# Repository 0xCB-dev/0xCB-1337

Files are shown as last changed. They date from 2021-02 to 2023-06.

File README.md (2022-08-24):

# 0xcb-1337
## Mechanical macropad with OLED running QMK

Licence | OSHWA
:-------------------------:|:-------------------------:
 | (https://certification.oshwa.org/de000121.html)

### Available here:

[KeebSupply](https://keeb.supply/products/0xcb-1337)

### QMK:

[keyboards/0xcb/1337/](https://github.com/qmk/qmk_firmware/tree/master/keyboards/0xcb/1337)

#### Flashing:

* `qmk clone`
* `cd qmk_firmware`
* `export LTO=Y`
* Press switch 1 while plugging in to go into dfu mode (or the reset button)
* `make 0xcb/1337:via:flash`

### Assembly:

You can use the [humanpnp](https://files.0xcb.dev/0xCB-1337/humanpnp.html) to easily place components.

### PCB:
KiCad 6 stable release - using these [libs](https://github.com/0xCB-dev/0xcb-libs)

[Schematic](https://github.com/0xCB-dev/0xcb-1337/blob/main/rev4.0/1337-v4.0.pdf)

Top | Bottom
:-------------------------:|:-------------------------:
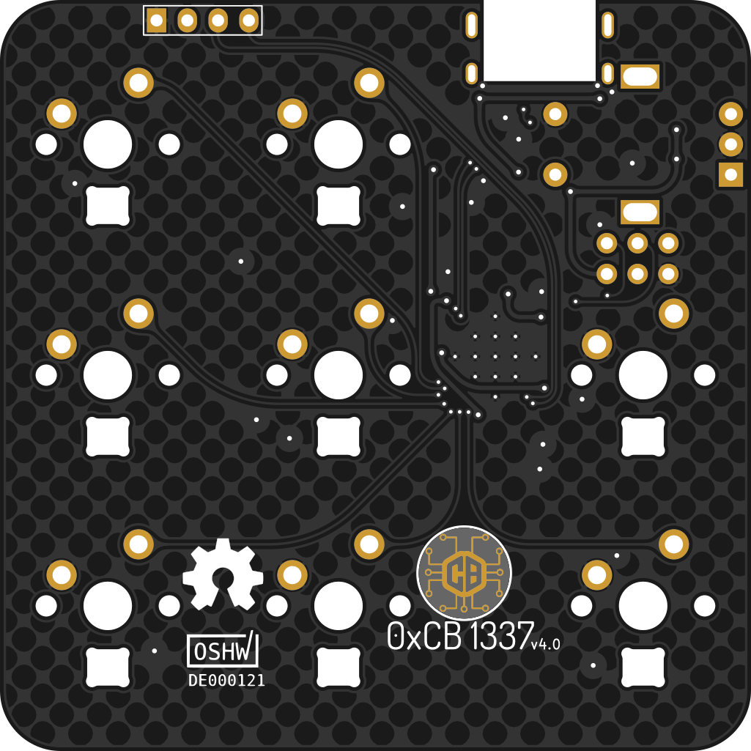
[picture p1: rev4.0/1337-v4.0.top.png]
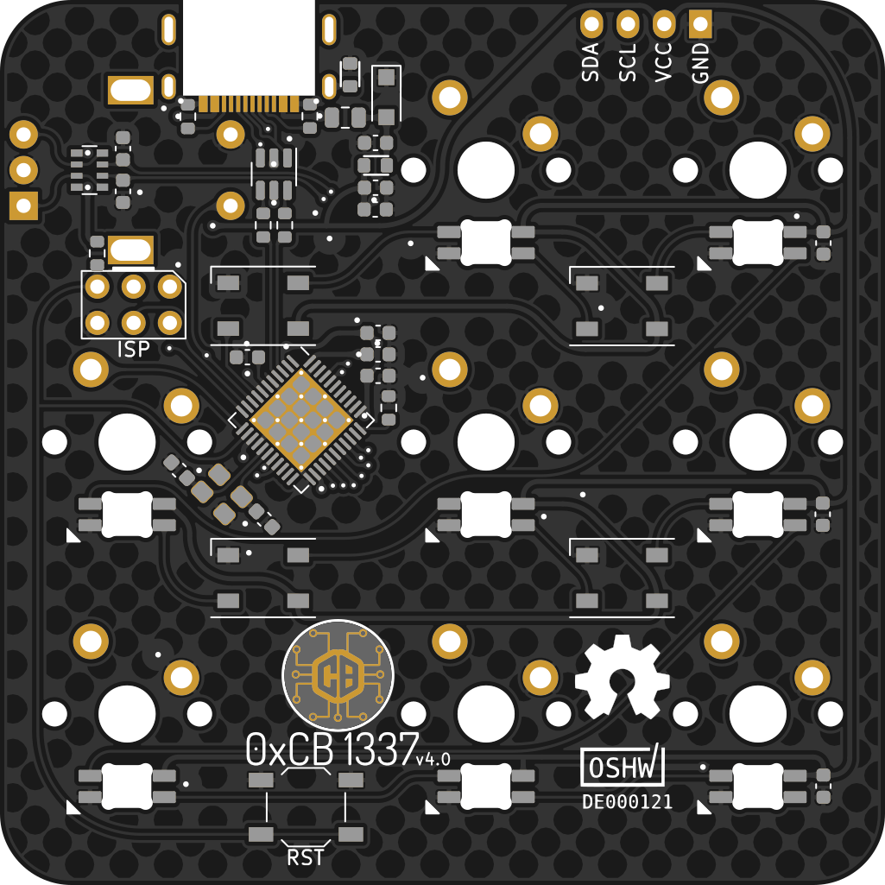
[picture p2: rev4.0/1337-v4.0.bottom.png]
  |  

### Case 3D files:

[STLs](https://github.com/0xCB-dev/0xcb-1337/tree/main/rev4.0/case/STL)

### PCB 3D files:

[FreeCAD](https://github.com/0xCB-dev/0xcb-1337/tree/main/rev4.0/1337-freecad.FCStd)

[STEP](https://github.com/0xCB-dev/0xcb-1337/tree/main/rev4.0/1337-v4.0.step)

[WRL](https://github.com/0xCB-dev/0xcb-1337/tree/main/rev4.0/1337-v4.0.wrl)

#### BOM:
 References                        | Value        | Quantity | Part Nb.            
-----------------------------------|--------------|----------|---------------------
 C2, C4, C6, C7, C8, C10, C12, C14 | 100n         | 8        | C478888             
 C3, C5, C9                        | 1u           | 3        | C29936              
 C11, C13                          | 22p          | 2        | C85969              
 C1                                | 10u          | 1        | C85713              
 R1, R2                            | 5.1k         | 2        | C23186              
 R3, R4                            | 22           | 2        | C174301             
 R5, R6                            | 10k          | 2        | C98220              
 D1, D2, D3, D4, D5, D6, D7, D8    | SK6812MINI-E | 8        | SK6812MINI-E        
 D10, D11, D12, D13                | WS2812B      | 4        | C114586             
 D9                                | SMF5.0CA     | 1        |  576-SMF5.0CA       
 U2                                | USBLC6-2SC6  | 1        | C7519               
 U3                                | ATMEGA32U4   | 1        | ATMEGA32U4RC-MU-ND  
 Y1                                | 16MHz        | 1        | C389842             
 F1                                | 1A           | 1        | C369150             
 SW1                               | SW_Push      | 1        | C318884             
 FB1, FB2                          | 600R         | 2        | C74330              
 RN1                               | 10k          | 1        | C109324             
 J1                                | USB_IN       | 1        | 900-2169900001CT-ND

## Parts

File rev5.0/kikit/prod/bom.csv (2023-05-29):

Comment | Designator | Footprint | LCSC
100n | C1,C2,C3,C4,C5,C6,C7,C8,C9,C12,C13,C14,C15,C16,C18,C19,C20,C21,C23,C24,C25,C27,C28,C29,C30,C31,C32,C33,C34,C35,C36,C38,C39,C41,C42,C43,C44,C45,C46,C47,C48,C49,C50,C51 | Capacitor_SMD:C_0201_0603Metric | C576431
1u | C22,C26 | Capacitor_SMD:C_0201_0603Metric | C76935
TPS2553DBVR | U3 | 0xcb:SOT95P280X145-6N | C55266
SK6812MINI-E | D1,D2,D3,D4,D5,D6,D7,D8 | 0xcb:MX_SK6812MINI-E | C5149201
WS2812B | D9,D10,D11,D12,D13,D14,D15,D16,D17,D18,D19,D20,D21,D22,D23,D24,D25,D26,D27,D28,D29,D30,D31 | LED_SMD:LED_WS2812B-2020_PLCC4_2.0x2.0mm | C2976072
MX | MX1,MX2,MX4,MX5,MX6,MX7,MX8,MX9 | 0xcb:SW_Hotswap_Kailh_1.00u | C5156480
10k | R4,R7 | Resistor_SMD:R_0201_0603Metric | C138117
USB_C_Receptacle_USB2.0 | J1 | 0xcb:GT-USB-7014C | C963373
12MHz | Y1 | Crystal:Crystal_SMD_2520-4Pin_2.5x2.0mm | C2149204
5k1 | R1,R2 | Resistor_SMD:R_0201_0603Metric | C473460
FPC | J2 | 0xcb:FFC-SMD_12P-P0.50_X05B20U12T | C388698
10u | C10,C11,C17 | Capacitor_SMD:C_0402_1005Metric | C15525
EC11 | MX3 | 0xcb:EC11 | C143817
27R | R3,R8,R9 | Resistor_SMD:R_0201_0603Metric | C273295
600R | FB1,FB2 | Resistor_SMD:R_0402_1005Metric | C160977
40k | R5 | Resistor_SMD:R_0201_0603Metric | C274875
10k | RN1 | Resistor_SMD:R_Array_Convex_4x0603 | C914793
XC6210B332MR-G | U2 | Package_TO_SOT_SMD:SOT-23-5 | C47719
15p | C37,C40 | Capacitor_SMD:C_0201_0603Metric | C85891
RP2040 | U6 | 0xcb:RP2040-QFN-56 | C2040
1k | R6,R10 | Resistor_SMD:R_0201_0603Metric | C138297
W25Q32JVUUIQ | U5 | 0xcb:W25Q32JVUUIQ | C2999380
1A | F1 | Fuse:Fuse_0603_1608Metric | C210357
USBLC6-2P6 | U1 | Package_TO_SOT_SMD:SOT-666 | C2827693
74LVC1T45 | U4 | Package_TO_SOT_SMD:SOT-563 | C352970

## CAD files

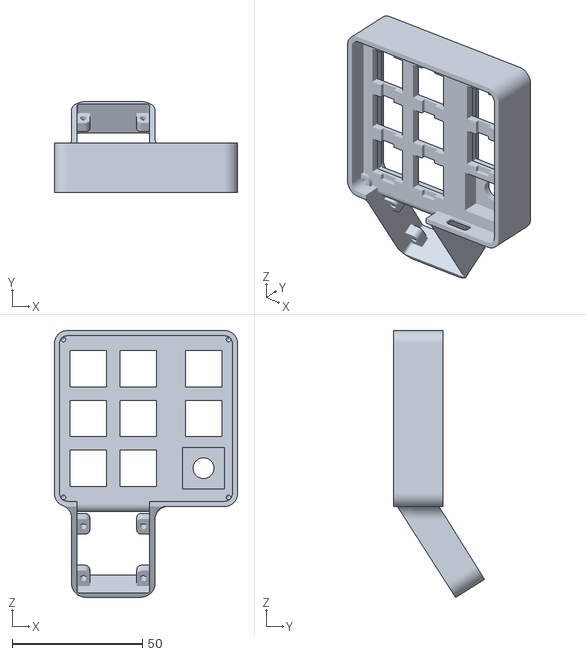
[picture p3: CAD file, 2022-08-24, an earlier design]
rev4.0/case/STL/Case.STL
70.4 x 35.0 x 102.5

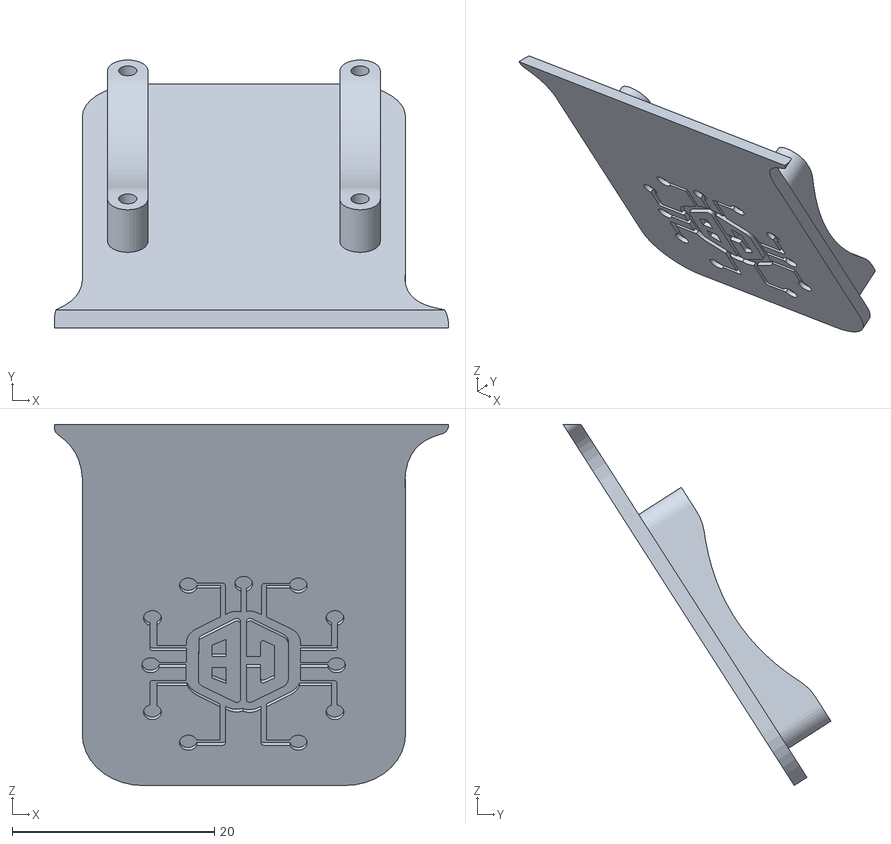
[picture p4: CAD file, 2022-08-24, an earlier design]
rev4.0/case/STL/Oled Bottom.STL
39.0 x 26.5 x 35.7

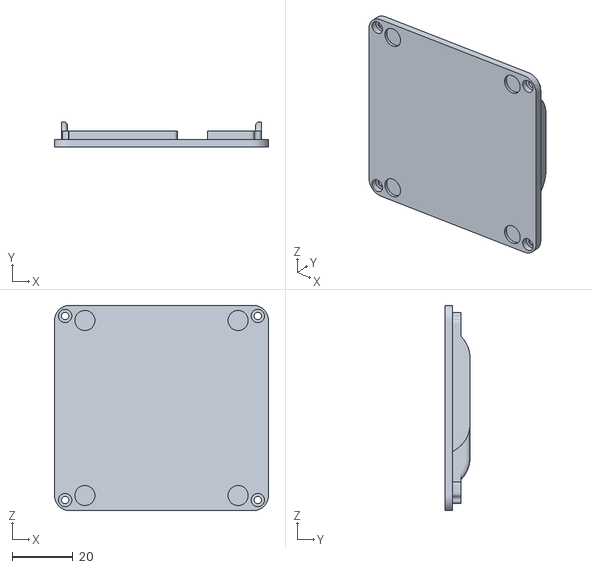
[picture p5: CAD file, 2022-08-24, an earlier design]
rev4.0/case/STL/Bottom.STL
70.4 x 8.25 x 67.6

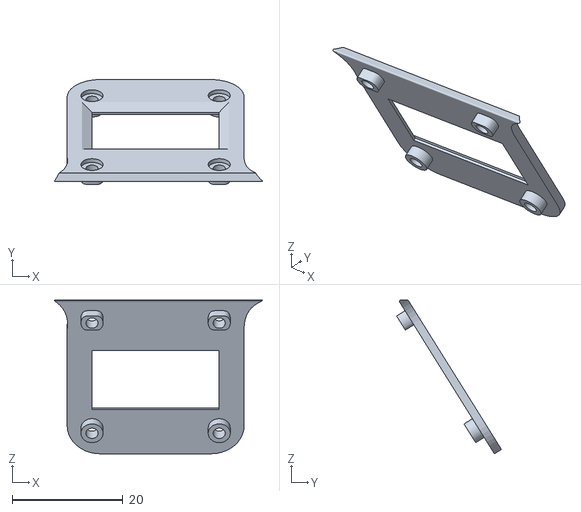
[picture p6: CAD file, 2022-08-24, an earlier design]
rev4.0/case/STL/Oled Top.STL
37.6 x 19.0 x 27.8

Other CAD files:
rev4.0/1337-v4.0-B_Silkscreen.dxf
rev4.0/1337-v4.0-F_Silkscreen.dxf

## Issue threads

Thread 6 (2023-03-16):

rev4 source code/keymap

nec4, 2023-03-16:
Hello, love the design of the macropad and it was fun to build. The macropad works fine when I use the hex provided in the rev4 release, but for some reason I cannot use the default keymap using QMK:

```
qmk flash -kb 0xcb/1337 -km default
```

Everything compiles and flashes just fine, but the OLED is different and the keymap seems broken (half the keys don't register and those that do are not sending the codes they are supposed to). I can re-flash the rev4 hex file and it works fine again, so I am pretty sure there is no issue with my soldering or the board. Am I using an old version of the PCB that is not compatible with the keymaps in the current QMK repo?

Conor-Burns, 2023-03-16:
Hi,
The rev 4 vial code is not upstream in qmk
Please try this instead https://github.com/0xCB-dev/keeb-firmware-source/tree/main/vial/1337

nec4, 2023-03-16:
Awesome, thanks!

Closed 2023-03-19.

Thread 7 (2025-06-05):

Is the encoder notched or linear/notchless?

strogonoff, 2025-06-05:
Sorry if this is documented, couldn’t find any info on this. Looking at the KeebSupply listing…

Conor-Burns, 2025-06-05:
The encoder is linear.

Closed 2025-06-05.

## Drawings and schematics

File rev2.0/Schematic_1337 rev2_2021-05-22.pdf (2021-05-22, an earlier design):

# ISP flash port

# OLED

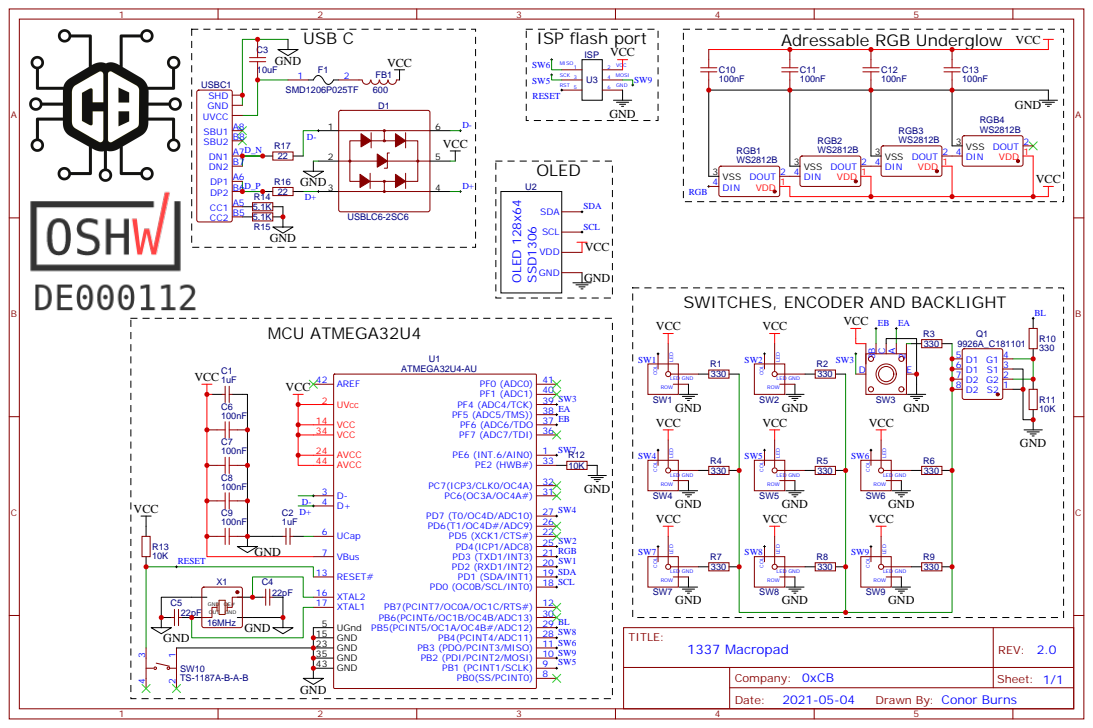
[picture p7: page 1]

SWITCHES, ENCODER AND BACKLIGHT

PB7(PCINT7/OC0A/OC1C/RTS#) 12
PB2 (PDI/PCINT2/MOSI) 10 PB3 (PDO/PCINT3/MISO) 11 PB4(PCINT4/ADC11) 28 PB5(PCINT5/OC1A/OC4B#/ADC12) 29 PB6(PCINT6/OC1B/OC4B/ADC13) 30

Drawn By: Conor Burns

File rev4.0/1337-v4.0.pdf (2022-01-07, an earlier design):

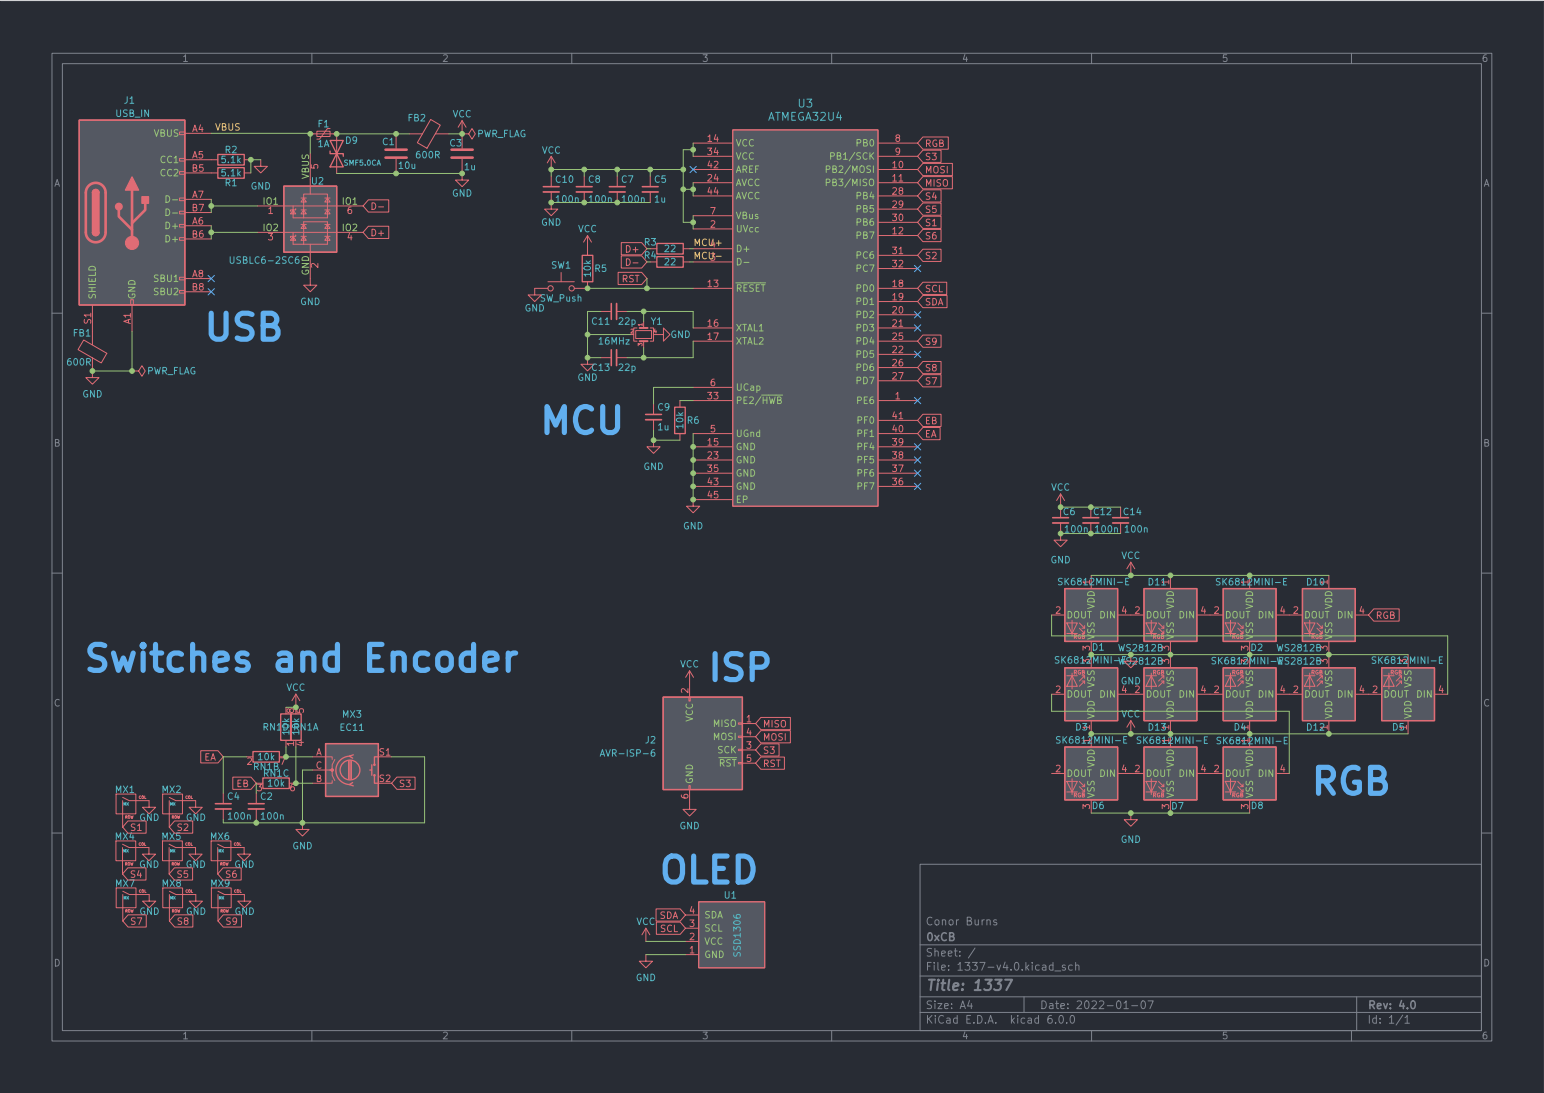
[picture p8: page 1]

2 SCK 3 MOSI 4 ~{RST} 5 GND

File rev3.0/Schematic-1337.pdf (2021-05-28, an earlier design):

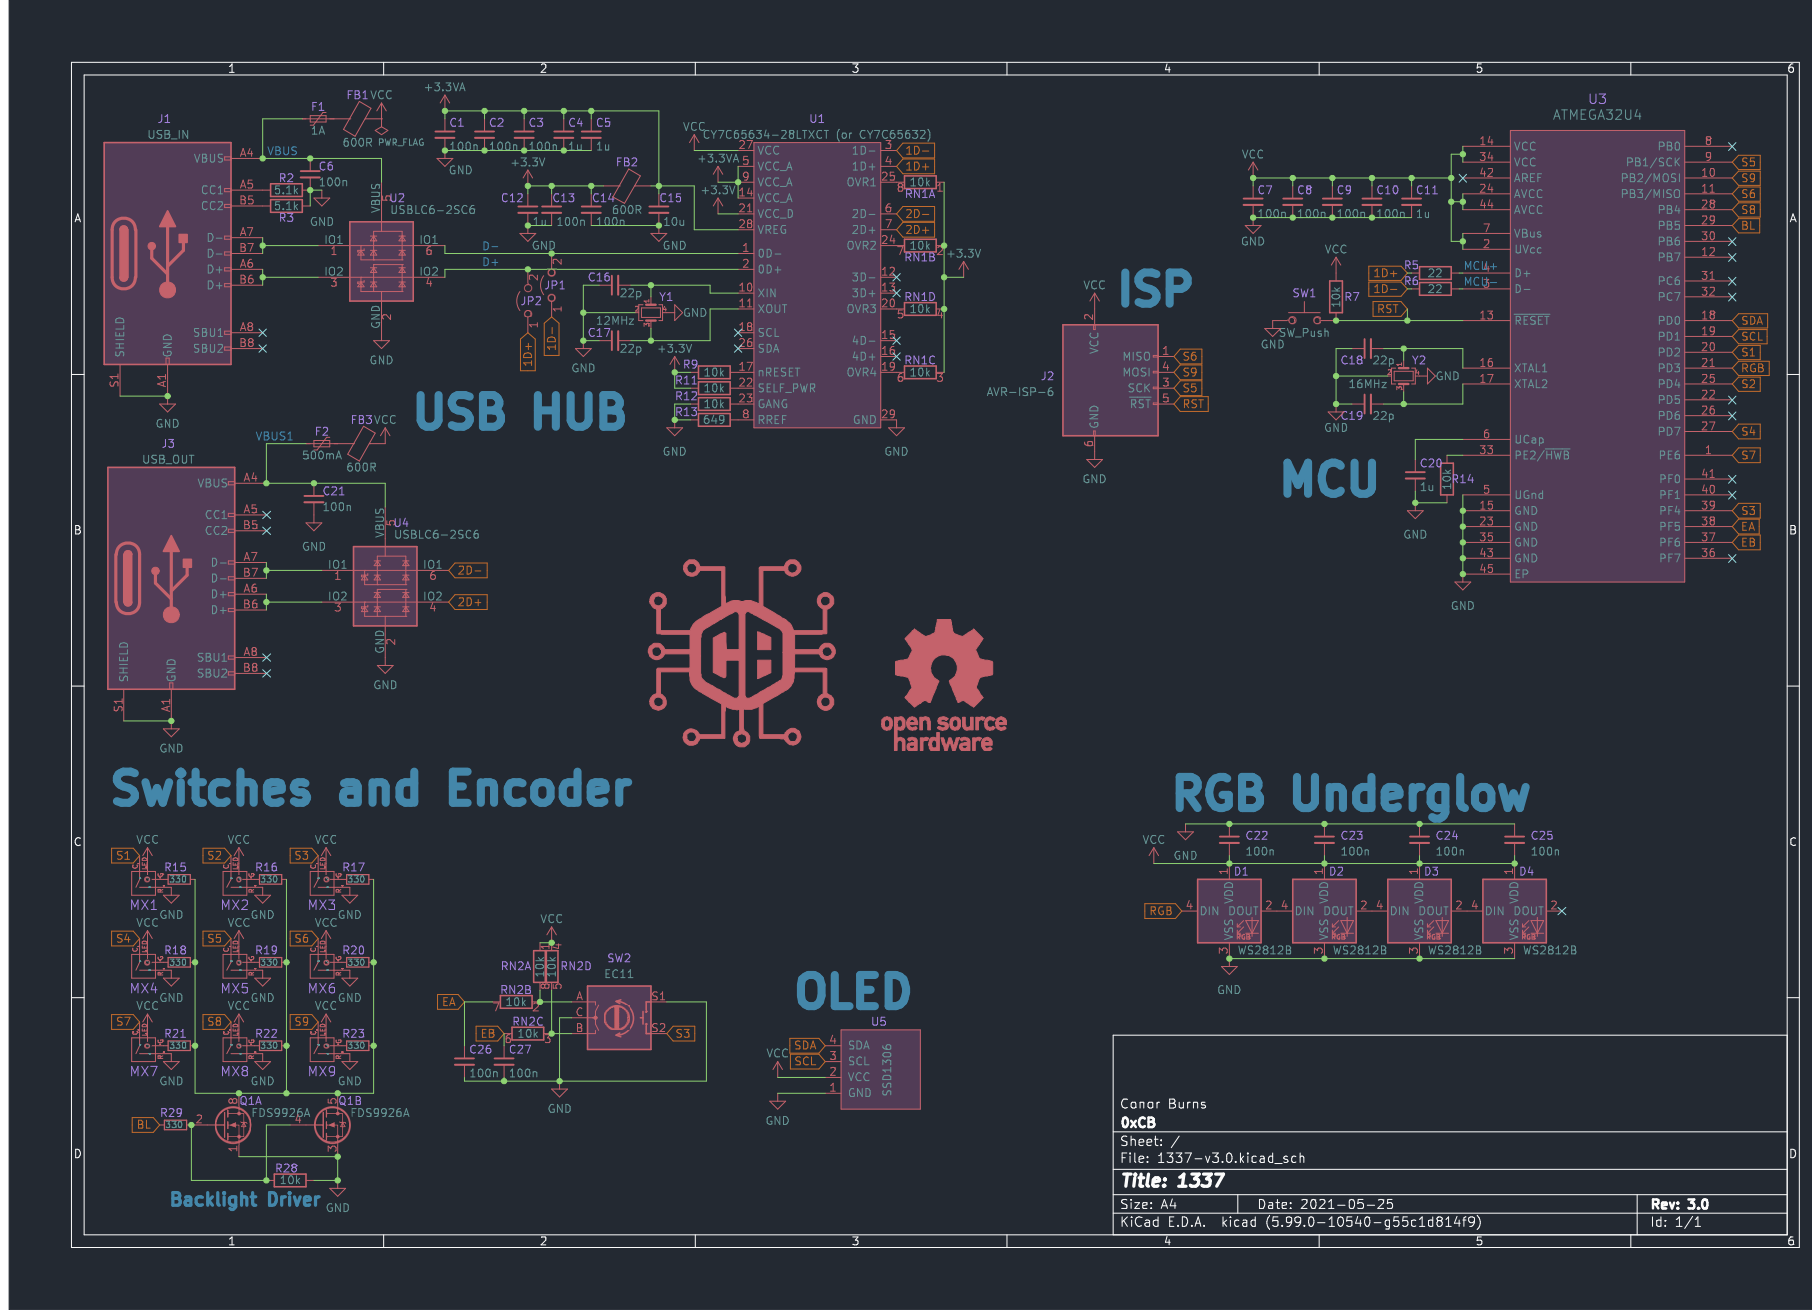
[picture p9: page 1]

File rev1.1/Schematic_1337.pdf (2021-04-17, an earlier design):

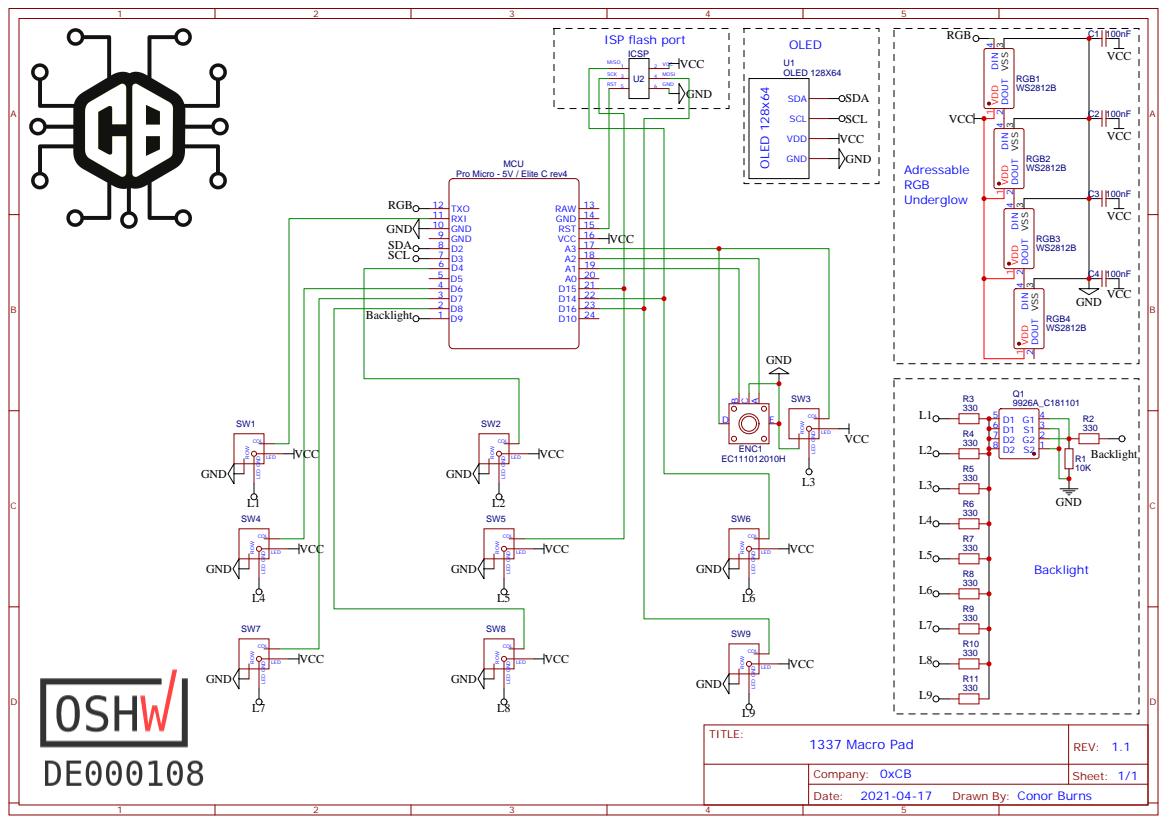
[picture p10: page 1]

Drawn By: Conor Burns

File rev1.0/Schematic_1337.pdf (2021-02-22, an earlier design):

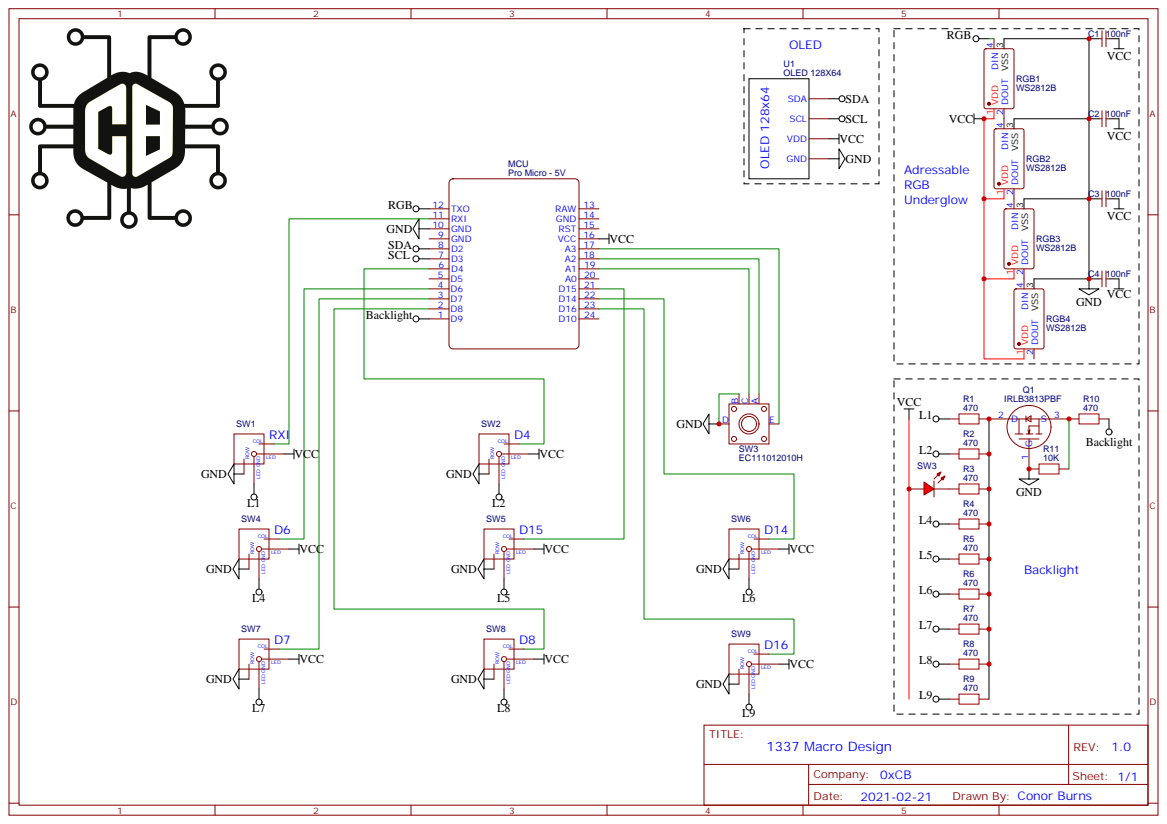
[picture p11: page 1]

Drawn By: Conor Burns

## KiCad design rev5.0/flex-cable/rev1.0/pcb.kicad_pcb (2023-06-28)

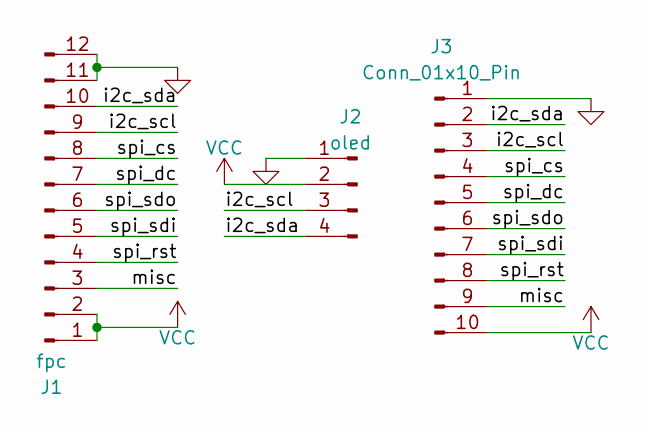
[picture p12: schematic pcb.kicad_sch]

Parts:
J1: fpc; FFC-SMD_12P-P0.50_X05B20U12T
J2: oled
J3: Conn_01x10_Pin; PinHeader_1x10_P2.54mm_Vertical

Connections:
/i2c_scl: J1.9, J2.3, J3.3
/i2c_sda: J1.10, J2.4, J3.2
/misc: J1.3, J3.9
/spi_cs: J1.8, J3.4
/spi_dc: J1.7, J3.5
/spi_rst: J1.4, J3.8
/spi_sdi: J1.5, J3.7
/spi_sdo: J1.6, J3.6
GND: J1.11, J1.12, J2.1, J3.1
VCC: J1.1, J1.2, J2.2, J3.10

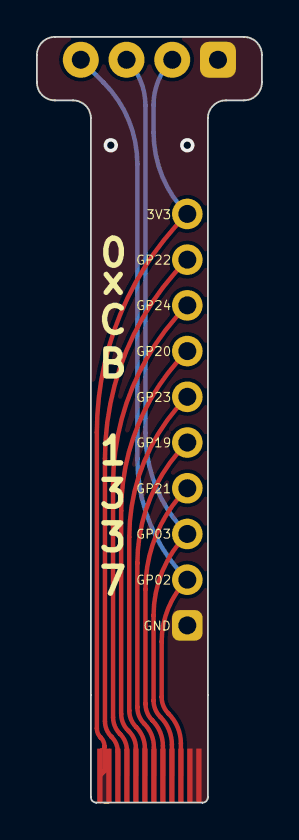
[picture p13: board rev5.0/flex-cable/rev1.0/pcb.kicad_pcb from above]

Board: 2 copper layers, 12.5 x 42.5 mm, 3 parts (1 on the bottom side), 10 nets.

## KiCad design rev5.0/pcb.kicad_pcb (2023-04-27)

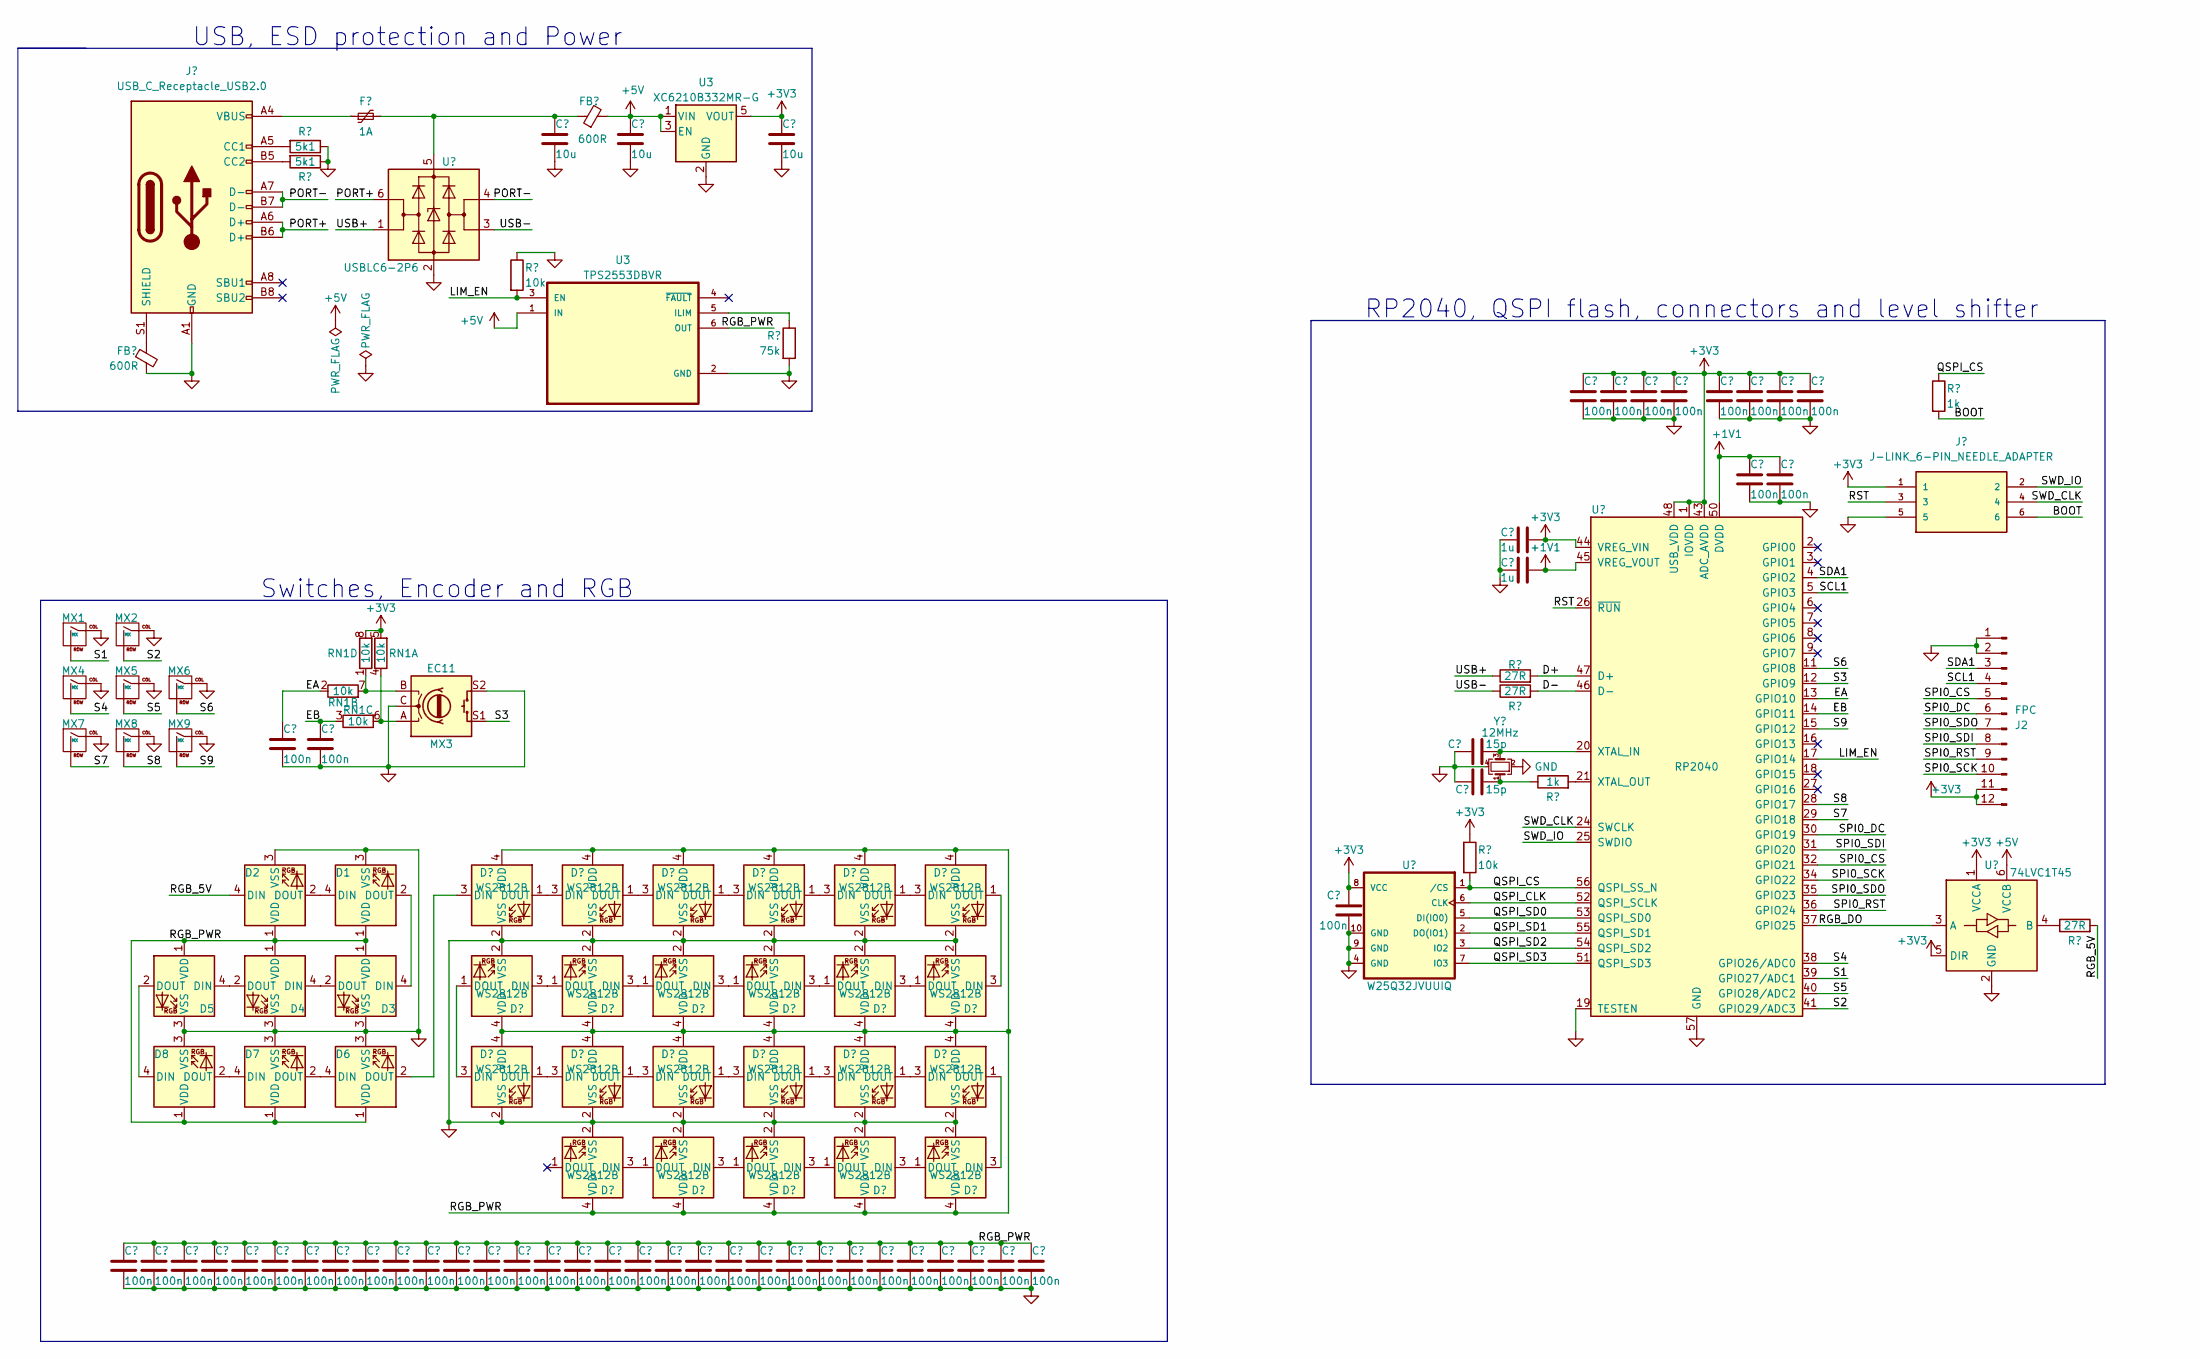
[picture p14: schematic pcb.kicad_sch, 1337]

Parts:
C1, C2, C3, C4, C5, C6, C7, C8, C9, C12, C13, C14, C15, C16, C18, C19, C20, C21, C23, C24, C25, C27, C28, C29, C30, C31, C32, C33, C34, C35, C36, C38, C39, C41, C42, C43, C44, C45, C46, C47, C48, C49, C50, C51: 100n; C_0201_0603Metric; MPN CL05B104KO5NNNC; LCSC C576431
C10, C11, C17: 10u; C_0402_1005Metric; MPN CL05A106MQ5NUNC; JLC Basic Y
C22, C26: 1u; C_0201_0603Metric; MPN CL05A105KA5NQNC; LCSC C237458
C37, C40: 15p; C_0201_0603Metric; MPN 0402CG150J500NT; LCSC C85891
D1, D2, D3, D4, D5, D6, D7, D8: SK6812MINI-E; MX_SK6812MINI-E; LCSC C5149201
D9, D10, D11, D12, D13, D14, D15, D16, D17, D18, D19, D20, D21, D22, D23, D24, D25, D26, D27, D28, D29, D30, D31: WS2812B; LED_WS2812B-2020_PLCC4_2.0x2.0mm; MPN WS2812B-2020; LCSC C2976072
F1: 1A; Fuse_0603_1608Metric; MPN MF-FSMF050X-2; LCSC C210357
FB1, FB2: 600R; R_0402_1005Metric; MPN BLM15PX601SN1D; JLC Basic N
J1: USB_C_Receptacle_USB2.0; GT-USB-7014C; MPN GT-USB-7014C; JLC Basic N
J2: FPC; FFC-SMD_12P-P0.50_X05B20U12T; LCSC C388698
J3: J-LINK_6-PIN_NEEDLE_ADAPTER; J-LINK_6-PIN_NEEDLE_ADAPTER_SMALL; MPN TC2030-ALT-NL
MX1, MX2, MX4, MX5, MX6, MX7, MX8, MX9: MX; SW_Hotswap_Kailh_1.00u; LCSC C5156480
MX3: EC11; Part Nb. PEC11L-4125F-S0020-ND; LCSC C143817
R1, R2: 5k1; R_0201_0603Metric; MPN 0402WGF5101TCE; LCSC C473460
R3, R8, R9: 27R; R_0201_0603Metric; MPN 0402WGF270JTCE; LCSC C273295
R4, R7: 10k; R_0201_0603Metric; MPN 0402WGF1002TCE; LCSC C138117
R5: 75k; R_0201_0603Metric; MPN 0402WGF1002TCE; LCSC C25744
R6, R10: 1k; R_0201_0603Metric; MPN 0402WGF1001TCE; LCSC C138165
RN1: 10k; R_Array_Convex_4x0603; Part Nb. MNR14103RTR-ND; LCSC C914793
U1: USBLC6-2P6; SOT-666; MPN USBLC6-2P6; JLC Basic N
U3: TPS2553DBVR; SOT95P280X145-6N; LCSC C55266
U4: 74LVC1T45; SOT-563; MPN SN74LVC1T45DRLR; JLC Basic N
U5: W25Q32JVUUIQ; MPN W25Q32JVUUIQ; LCSC C2999380
U6: RP2040; RP2040-QFN-56; MPN RP2040; LCSC C2040
Y1: 12MHz; Crystal_SMD_2520-4Pin_2.5x2.0mm; MPN 2TJ412000HYGBC; LCSC C2149204

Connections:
+1V1: C22.2, C25.1, C39.1, U6.23 (DVDD), U6.45 (VREG_VOUT), U6.50 (DVDD)
/BOOT: J3.6, R6.2
/D+: R8.2, U6.47 (D+)
/D-: R9.2, U6.46 (D-)
/EA: C7.1, RN1.2 (R2.1), U6.13 (GPIO10)
/EB: C8.1, RN1.3 (R3.1), U6.14 (GPIO11)
/PORT+: J1.A6 (D+), J1.B6 (D+), U1.6 (I/O1)
/PORT-: J1.A7 (D-), J1.B7 (D-), U1.4 (I/O2)
/QSPI_CLK: U5.6 (CLK), U6.52 (QSPI_SCLK)
/QSPI_CS: R6.1, R7.2, U5.1 (/CS), U6.56 (QSPI_SS_N)
/QSPI_SD0: U5.5 (DI(IO0)), U6.53 (QSPI_SD0)
/QSPI_SD1: U5.2 (DO(IO1)), U6.55 (QSPI_SD1)
/QSPI_SD2: U5.3 (IO2), U6.54 (QSPI_SD2)
/QSPI_SD3: U5.7 (IO3), U6.51 (QSPI_SD3)
/RGB_5V: D2.4 (DIN), R3.2
/RGB_DO: U4.3 (A), U6.37 (GPIO25)
/RGB_PWR: C1.1, C2.1, C3.1, C4.1, C5.1, C6.1, C9.1, C12.1, C13.1, C14.1, C15.1, C16.1, C18.1, C19.1, C20.1, C28.1, C29.1, C30.1, C31.1, C36.1, C41.1, C42.1, C43.1, C44.1, C45.1, C46.1, C47.1, C48.1, C49.1, C50.1, C51.1, D1.1 (VDD), D2.1 (VDD), D3.1 (VDD), D4.1 (VDD), D5.1 (VDD), D6.1 (VDD), D7.1 (VDD), D8.1 (VDD), D9.4 (VDD), D10.4 (VDD), D11.4 (VDD), D12.4 (VDD), D13.4 (VDD), D14.4 (VDD), D15.4 (VDD), D16.4 (VDD), D17.4 (VDD), D18.4 (VDD), D19.4 (VDD), D20.4 (VDD), D21.4 (VDD), D22.4 (VDD), D23.4 (VDD), D24.4 (VDD), D25.4 (VDD), D26.4 (VDD), D27.4 (VDD), D28.4 (VDD), D29.4 (VDD), D30.4 (VDD), D31.4 (VDD), U3.6 (OUT)
/RST: J3.3, U6.26 (~RUN)
/S1: MX1.2 (ROW), U6.39 (GPIO27/ADC1)
/S2: MX2.2 (ROW), U6.41 (GPIO29/ADC3)
/S3: MX3.S1, U6.12 (GPIO9)
/S4: MX4.2 (ROW), U6.38 (GPIO26/ADC0)
/S5: MX5.2 (ROW), U6.40 (GPIO28/ADC2)
/S6: MX6.2 (ROW), U6.11 (GPIO8)
/S7: MX7.2 (ROW), U6.29 (GPIO18)
/S8: MX8.2 (ROW), U6.28 (GPIO17)
/S9: MX9.2 (ROW), U6.15 (GPIO12)
/SCL1: J2.4, U6.5 (GPIO3)
/SDA1: J2.3, U6.4 (GPIO2)
/SPI0_CS: J2.5, U6.32 (GPIO21)
/SPI0_DC: J2.6, U6.30 (GPIO19)
/SPI0_RST: J2.9, U6.36 (GPIO24)
/SPI0_SCK: J2.10, U6.34 (GPIO22)
/SPI0_SDI: J2.8, U6.31 (GPIO20)
/SPI0_SDO: J2.7, U6.35 (GPIO23)
/SWD_CLK: J3.4, U6.24 (SWCLK)
/SWD_IO: J3.2, U6.25 (SWDIO)
/USB+: R8.1, U1.1 (I/O1)
/USB-: R9.1, U1.3 (I/O2)
GND: C1.2, C2.2, C3.2, C4.2, C5.2, C6.2, C7.2, C8.2, C9.2, C10.2, C11.2, C12.2, C13.2, C14.2, C15.2, C16.2, C17.2, C18.2, C19.2, C20.2, C21.2, C22.1, C23.2, C24.2, C25.2, C26.1, C27.2, C28.2, C29.2, C30.2, C31.2, C32.2, C33.2, C34.2, C35.2, C36.2, C37.1, C38.2, C39.2, C40.1, C41.2, C42.2, C43.2, C44.2, C45.2, C46.2, C47.2, C48.2, C49.2, C50.2, C51.2, D1.3 (VSS), D2.3 (VSS), D3.3 (VSS), D4.3 (VSS), D5.3 (VSS), D6.3 (VSS), D7.3 (VSS), D8.3 (VSS), D9.2 (VSS), D10.2 (VSS), D11.2 (VSS), D12.2 (VSS), D13.2 (VSS), D14.2 (VSS), D15.2 (VSS), D16.2 (VSS), D17.2 (VSS), D18.2 (VSS), D19.2 (VSS), D20.2 (VSS), D21.2 (VSS), D22.2 (VSS), D23.2 (VSS), D24.2 (VSS), D25.2 (VSS), D26.2 (VSS), D27.2 (VSS), D28.2 (VSS), D29.2 (VSS), D30.2 (VSS), D31.2 (VSS), FB1.2, J1.A1 (GND), J1.A12 (GND), J1.B1 (GND), J1.B12 (GND), J2.1, J2.2, J3.5, MX1.1 (COL), MX2.1 (COL), MX3.C, MX3.S2, MX4.1 (COL), MX5.1 (COL), MX6.1 (COL), MX7.1 (COL), MX8.1 (COL), MX9.1 (COL), R1.1, R2.1, R4.1, R5.2, U1.2 (GND), U3.2 (GND), U4.2 (GND), U5.4 (GND), U5.9 (GND), U5.10 (GND), U6.19 (TESTEN), U6.57 (GND), Y1.2, Y1.4; also elsewhere on the board
unnamed: C40.2, R10.1, Y1.1
unnamed: D1.4 (DIN), D2.2 (DOUT)
unnamed: D1.2 (DOUT), D3.4 (DIN)
unnamed: D3.2 (DOUT), D4.4 (DIN)
unnamed: D4.2 (DOUT), D5.4 (DIN)
unnamed: D5.2 (DOUT), D8.4 (DIN)
unnamed: D6.4 (DIN), D7.2 (DOUT)
unnamed: D7.4 (DIN), D8.2 (DOUT)
unnamed: D9.1 (DOUT), D10.3 (DIN)
unnamed: D10.1 (DOUT), D11.3 (DIN)
unnamed: D11.1 (DOUT), D12.3 (DIN)
unnamed: D12.1 (DOUT), D13.3 (DIN)
unnamed: D13.1 (DOUT), D15.3 (DIN)
unnamed: D14.3 (DIN), D16.1 (DOUT)
unnamed: D9.3 (DIN), D14.1 (DOUT)
unnamed: D15.1 (DOUT), D17.3 (DIN)
unnamed: D16.3 (DIN), D18.1 (DOUT)
unnamed: D17.1 (DOUT), D19.3 (DIN)
unnamed: D18.3 (DIN), D20.1 (DOUT)
unnamed: D19.1 (DOUT), D21.3 (DIN)
unnamed: D20.3 (DIN), D22.1 (DOUT)
unnamed: D21.1 (DOUT), D23.3 (DIN)
unnamed: D22.3 (DIN), D24.1 (DOUT)
unnamed: D23.1 (DOUT), D25.3 (DIN)
unnamed: D24.3 (DIN), D26.1 (DOUT)
unnamed: D26.3 (DIN), D27.1 (DOUT)
unnamed: D27.3 (DIN), D28.1 (DOUT)
unnamed: D28.3 (DIN), D29.1 (DOUT)
unnamed: D29.3 (DIN), D30.1 (DOUT)
unnamed: D30.3 (DIN), D31.1 (DOUT)
unnamed: D6.2 (DOUT), D31.3 (DIN)
unnamed: F1.1, J1.A4 (VBUS), J1.A9 (VBUS), J1.B4 (VBUS), J1.B9 (VBUS)
unnamed: J1.A5 (CC1), R2.2
unnamed: J1.B5 (CC2), R1.2
unnamed: FB1.1, J1.S1 (SHIELD)
unnamed: MX3.B, RN1.1 (R1.1), RN1.7 (R2.2)
unnamed: MX3.A, RN1.4 (R4.1), RN1.6 (R3.2)
unnamed: C10.1, F1.2, FB2.1, U1.5 (VBUS)
unnamed: R3.1, U4.4 (B)
unnamed: C37.2, U6.20 (XTAL_IN), Y1.3
unnamed: R10.2, U6.21 (XTAL_OUT)

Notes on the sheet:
Switches, Encoder and RGB
USB, ESD protection and Power
RP2040, QSPI flash, connectors and level shifter

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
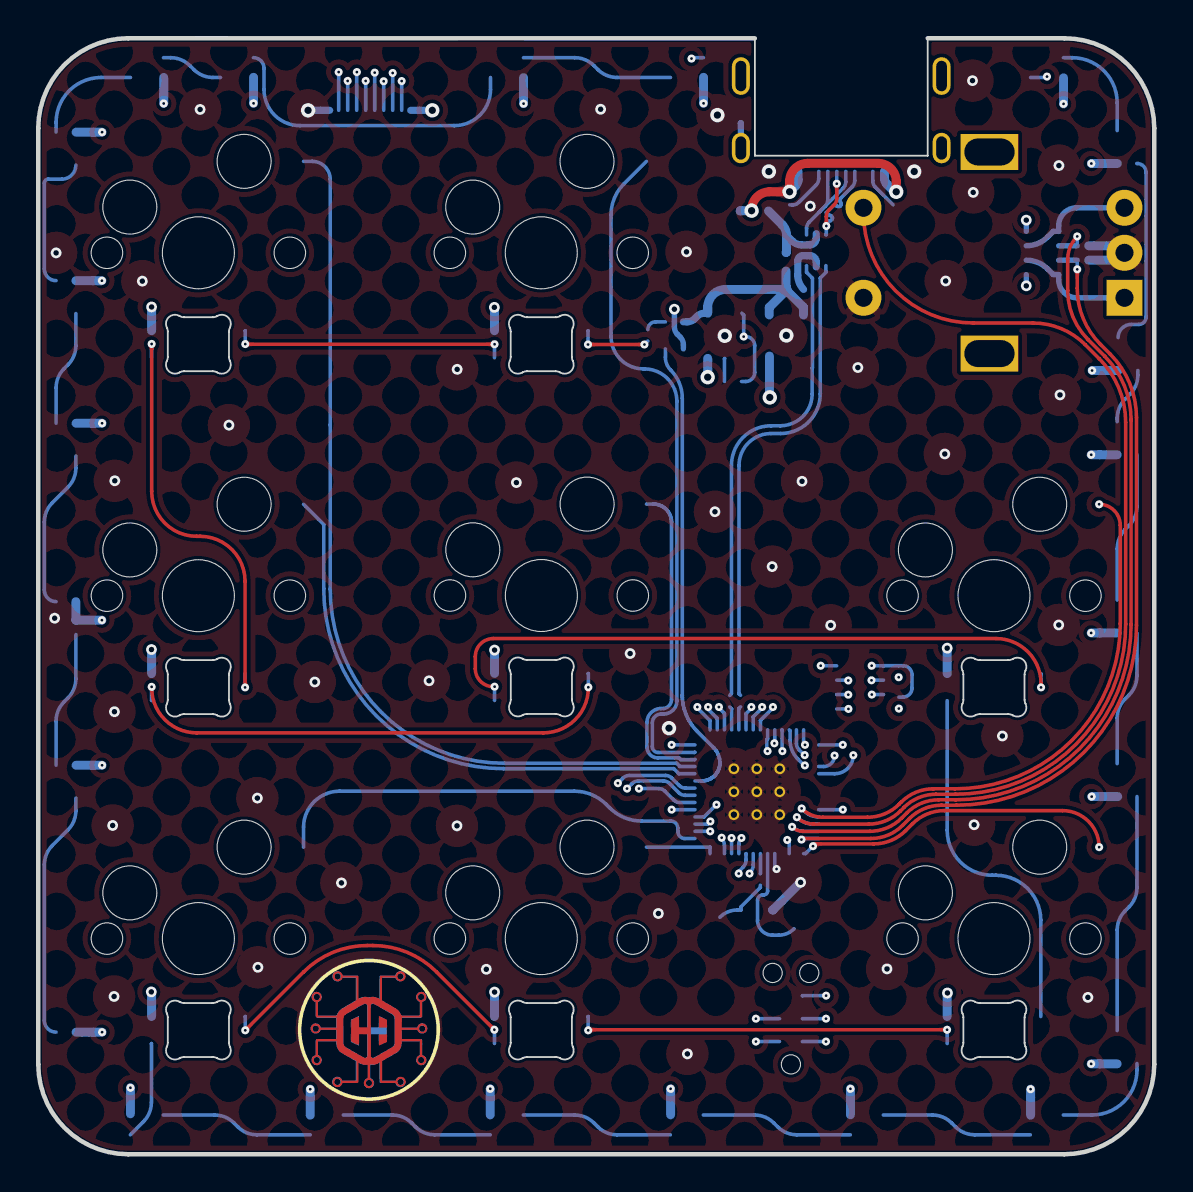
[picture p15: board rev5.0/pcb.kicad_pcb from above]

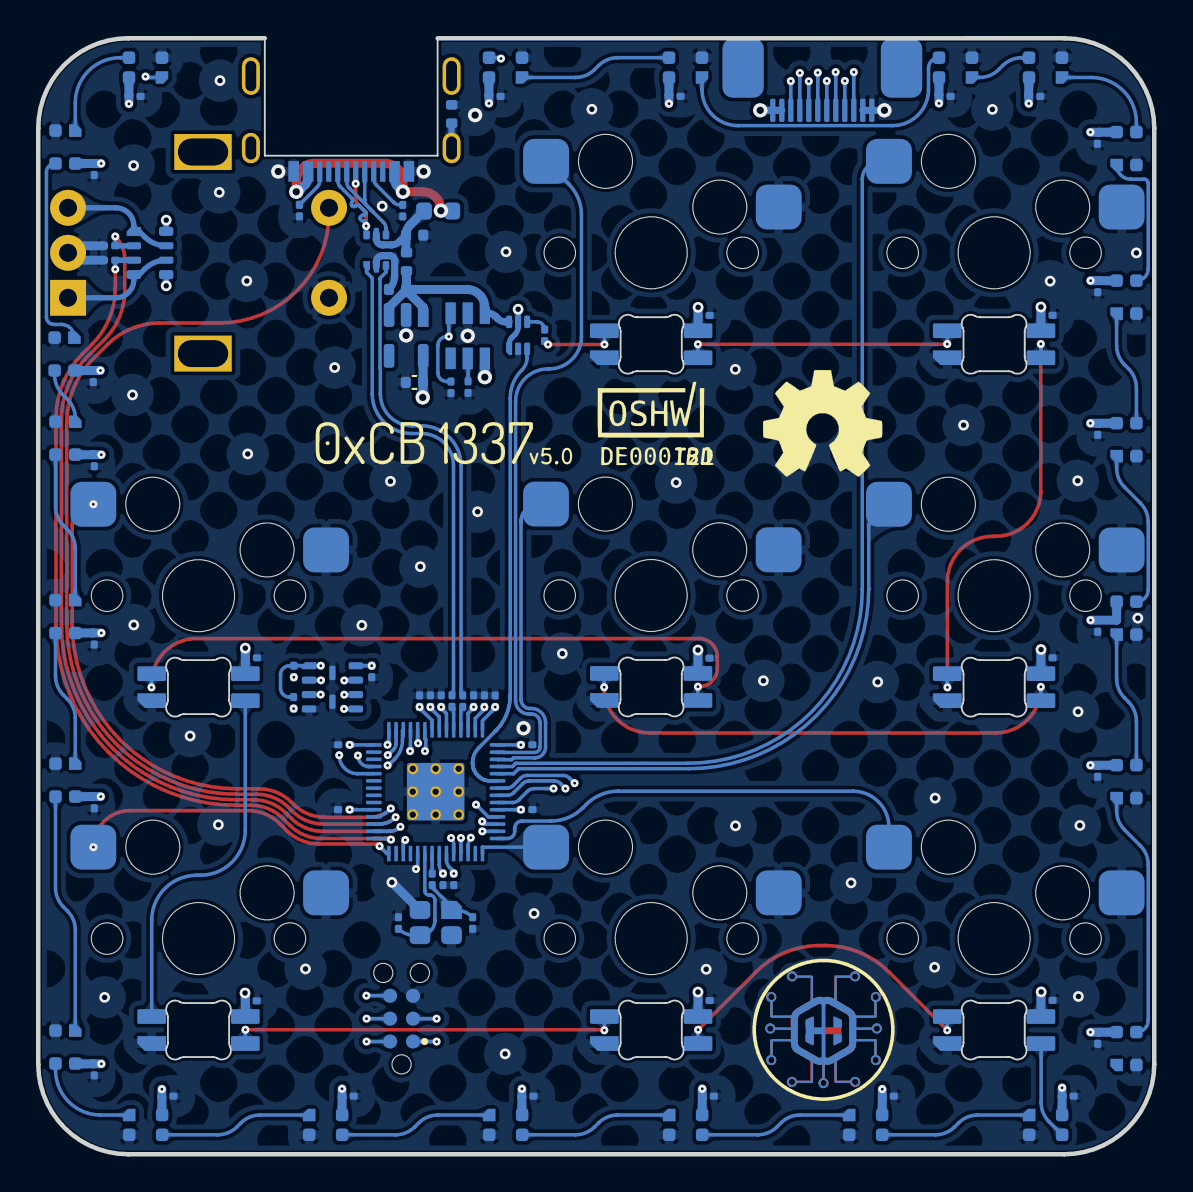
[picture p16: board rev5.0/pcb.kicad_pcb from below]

Board: 4 copper layers, 62.0 x 62.0 mm, 116 parts (115 on the bottom side), 85 nets.

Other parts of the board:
U2: XC6210B332MR-G; SOT-23-5
kibuzzard-1: G***; kibuzzard-61BA68AC

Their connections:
GND: U2.2 (GND); also elsewhere on the board

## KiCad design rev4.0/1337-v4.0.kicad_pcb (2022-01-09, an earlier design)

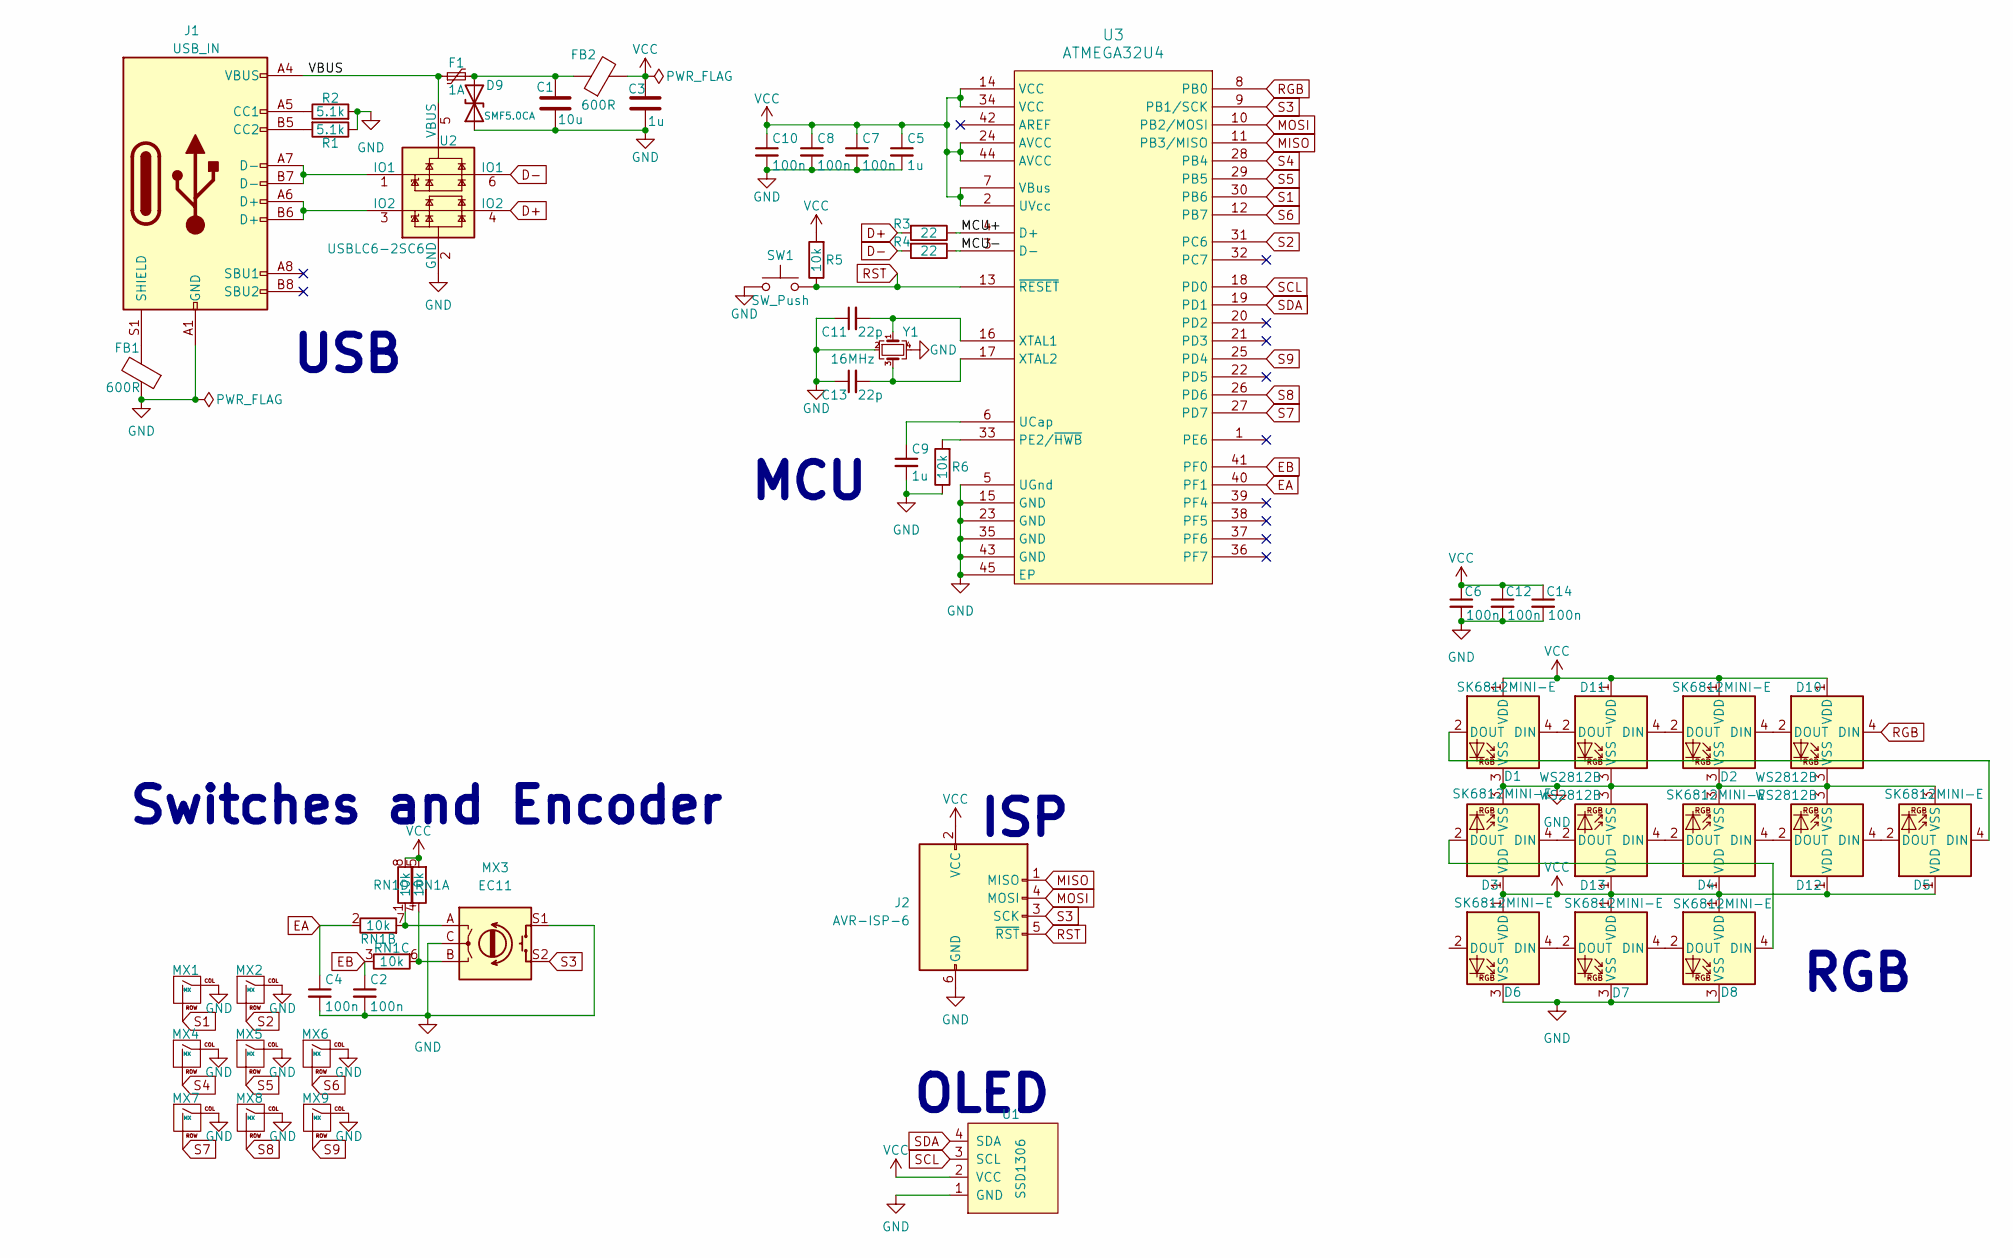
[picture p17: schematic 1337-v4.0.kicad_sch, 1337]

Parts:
C1: 10u; C_0603_1608Metric
C2, C4, C6, C7, C8, C10, C12, C14: 100n; C_0603_1608Metric; Part Nb. 478-5266-1-ND
C3: 1u; C_0603_1608Metric
C5, C9: 1u; C_0603_1608Metric; Part Nb. 1276-1102-1-ND
C11, C13: 22p; C_0603_1608Metric; Part Nb. 478-1167-1-ND
D1, D2, D3, D4, D5, D6, D7, D8: SK6812MINI-E; MX_SK6812MINI-E
D9: SMF5.0CA; D_SOD-123F
D10, D11, D12, D13: WS2812B; LED_WS2812B_PLCC4_5.0x5.0mm_P3.2mm; Part Nb. 1568-COM-16347CT-ND
F1: 1A; Fuse_0805_2012Metric; Part Nb. 507-1815-1-ND
FB1: 600R; Ferrite_Bead_0603; Part Nb. 732-1593-1-ND
FB2: 600R; Ferrite_Bead_0603
J1: USB_IN; molex2169900001; Part Nb. 900-2169900002CT-ND
J2: AVR-ISP-6; AVR_PROG_2.54_THT
MX1, MX2, MX4, MX5, MX6, MX7, MX8, MX9: MX; SW_Cherry_MX_PCB_1.00u
MX3: EC11; Part Nb. PEC11L-4125F-S0020-ND
R1, R2: 5.1k; R_0603_1608Metric; Part Nb. P5.1KDBCT-ND
R3, R4: 22; R_0603_1608Metric; Part Nb. A130081CT-ND
R5, R6: 10k; R_0603_1608Metric; Part Nb. RHM10KADCT-ND
RN1: 10k; R_Array_Convex_4x0603; Part Nb. MNR14103RTR-ND
SW1: SW_Push; SW_SPST_TL3342; Part Nb. EG2531CT-ND
U1: SSD1306; 128x64OLED
U2: USBLC6-2SC6; SOT-23-6; Part Nb. 497-5235-1-ND
U3: ATMEGA32U4; QFN-44-1EP_7x7mm_P0.5mm_EP5.2x5.2mm_ThermalVias; Part Nb. ATMEGA32U4RC-MURCT-ND
Y1: 16MHz; Crystal_SMD_3225-4Pin_3.2x2.5mm; Part Nb. XC2060CT-ND

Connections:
/MCU+: R3.1, U3.4 (D+)
/MCU-: R4.1, U3.3 (D-)
/VBUS: F1.1, J1.A4 (VBUS), J1.A9 (VBUS), J1.B4 (VBUS), J1.B9 (VBUS), U2.5 (VBUS)
D+: R3.2, U2.4 (IO2)
D-: R4.2, U2.6 (IO1)
EA: C4.1, RN1.2 (R2.1), U3.40 (PF1)
EB: C2.1, RN1.3 (R3.1), U3.41 (PF0)
GND: C1.2, C2.2, C3.2, C4.2, C5.2, C6.2, C7.2, C8.2, C9.2, C10.2, C11.1, C12.2, C13.1, C14.2, D1.3 (VSS), D2.3 (VSS), D3.3 (VSS), D4.3 (VSS), D5.3 (VSS), D6.3 (VSS), D7.3 (VSS), D8.3 (VSS), D9.1 (A1), D10.3 (VSS), D11.3 (VSS), D12.3 (VSS), D13.3 (VSS), FB1.1, J1.A1 (GND), J1.A12 (GND), J1.B1 (GND), J1.B12 (GND), J2.6 (GND), MX1.1 (COL), MX2.1 (COL), MX3.C, MX3.S1, MX4.1 (COL), MX5.1 (COL), MX6.1 (COL), MX7.1 (COL), MX8.1 (COL), MX9.1 (COL), R1.1, R2.2, R6.1, SW1.1, U1.1 (GND), U2.2 (GND), U3.5 (UGnd), U3.15 (GND), U3.23 (GND), U3.35 (GND), U3.43 (GND), U3.45 (EP), Y1.2, Y1.4
MISO: J2.1 (MISO), U3.11 (PB3/MISO)
MOSI: J2.4 (MOSI), U3.10 (PB2/MOSI)
unnamed: C1.1, D9.2 (A2), F1.2, FB2.1
unnamed: C9.1, U3.6 (UCap)
unnamed: C11.2, U3.16 (XTAL1), Y1.1
unnamed: C13.2, U3.17 (XTAL2), Y1.3
unnamed: D1.2 (DOUT), D5.4 (DIN)
unnamed: D1.4 (DIN), D11.2 (DOUT)
unnamed: D3.2 (DOUT), D8.4 (DIN)
unnamed: D6.4 (DIN), D7.2 (DOUT)
unnamed: D7.4 (DIN), D8.2 (DOUT)
unnamed: D2.4 (DIN), D10.2 (DOUT)
unnamed: D2.2 (DOUT), D11.4 (DIN)
unnamed: D4.4 (DIN), D12.2 (DOUT)
unnamed: D5.2 (DOUT), D12.4 (DIN)
unnamed: D3.4 (DIN), D13.2 (DOUT)
unnamed: D4.2 (DOUT), D13.4 (DIN)
unnamed: FB1.2, J1.S1 (SHIELD)
unnamed: J1.A5 (CC1), R2.1
unnamed: J1.A6 (D+), J1.B6 (D+), U2.3 (IO2)
unnamed: J1.A7 (D-), J1.B7 (D-), U2.1 (IO1)
unnamed: J1.B5 (CC2), R1.2
unnamed: MX3.A, RN1.1 (R1.1), RN1.7 (R2.2)
unnamed: MX3.B, RN1.4 (R4.1), RN1.6 (R3.2)
unnamed: R6.2, U3.33 (PE2/~HWB)
RGB: D10.4 (DIN), U3.8 (PB0)
RST: J2.5 (~RST), R5.1, SW1.2, U3.13 (~RESET)
S1: MX1.2 (ROW), U3.30 (PB6)
S2: MX2.2 (ROW), U3.31 (PC6)
S3: J2.3 (SCK), MX3.S2, U3.9 (PB1/SCK)
S4: MX4.2 (ROW), U3.28 (PB4)
S5: MX5.2 (ROW), U3.29 (PB5)
S6: MX6.2 (ROW), U3.12 (PB7)
S7: MX7.2 (ROW), U3.27 (PD7)
S8: MX8.2 (ROW), U3.26 (PD6)
S9: MX9.2 (ROW), U3.25 (PD4)
SCL: U1.3 (SCL), U3.18 (PD0)
SDA: U1.4 (SDA), U3.19 (PD1)
VCC: C3.1, C5.1, C6.1, C7.1, C8.1, C10.1, C12.1, C14.1, D1.1 (VDD), D2.1 (VDD), D3.1 (VDD), D4.1 (VDD), D5.1 (VDD), D6.1 (VDD), D7.1 (VDD), D8.1 (VDD), D10.1 (VDD), D11.1 (VDD), D12.1 (VDD), D13.1 (VDD), FB2.2, J2.2 (VCC), R5.2, RN1.5 (R4.2), RN1.8 (R1.2), U1.2 (VCC), U3.2 (UVcc), U3.7 (VBus), U3.14 (VCC), U3.24 (AVCC), U3.34 (VCC), U3.44 (AVCC)

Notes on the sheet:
RGB
ISP
OLED
USB
MCU
Switches and Encoder

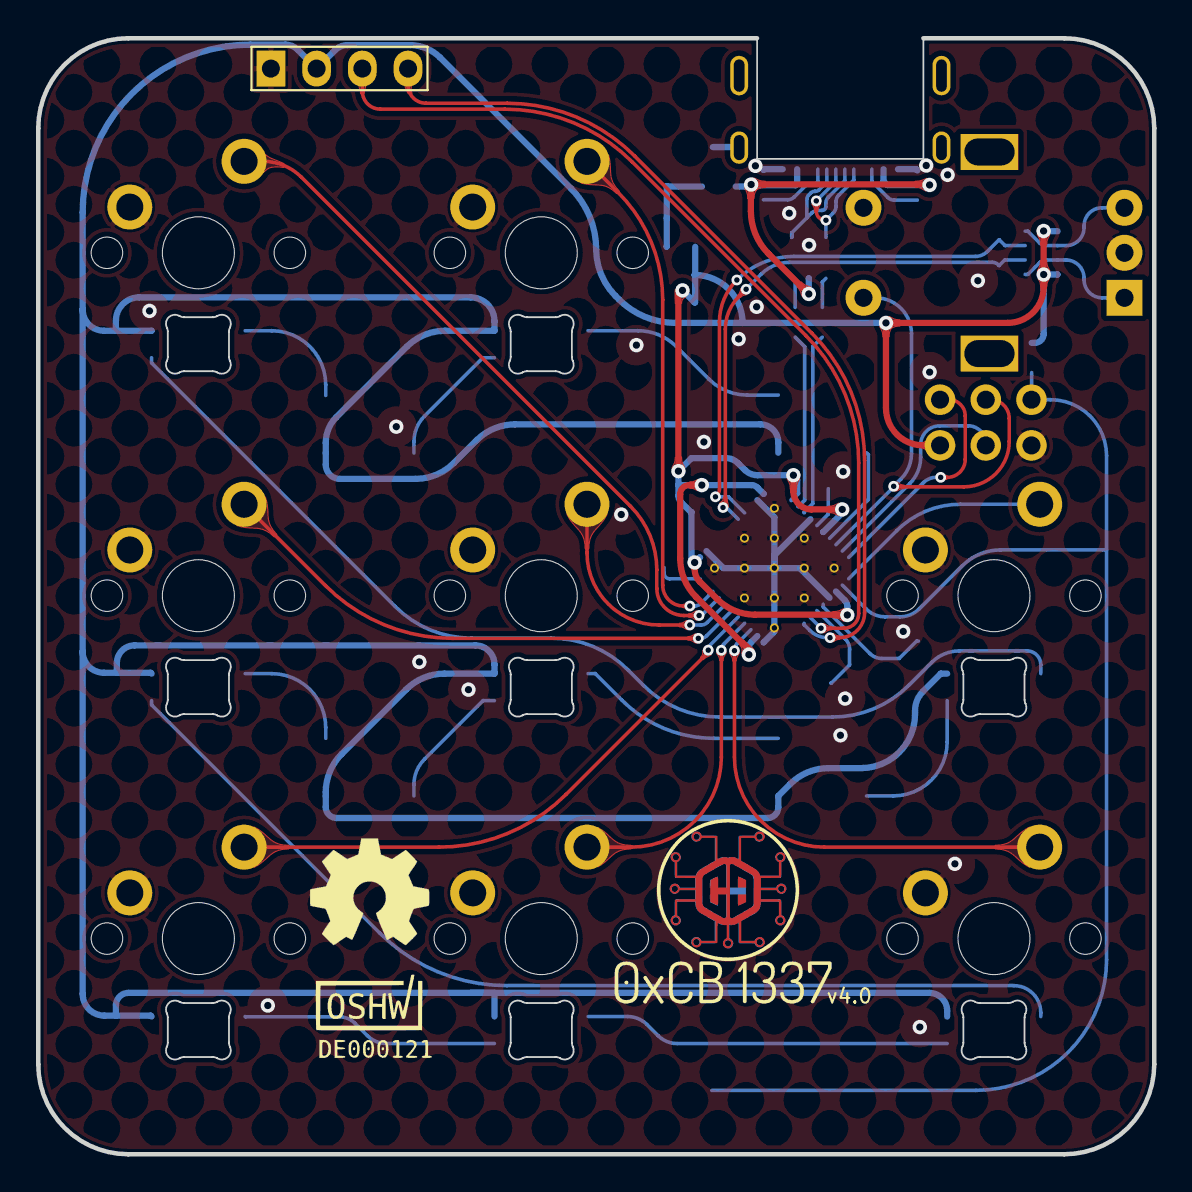
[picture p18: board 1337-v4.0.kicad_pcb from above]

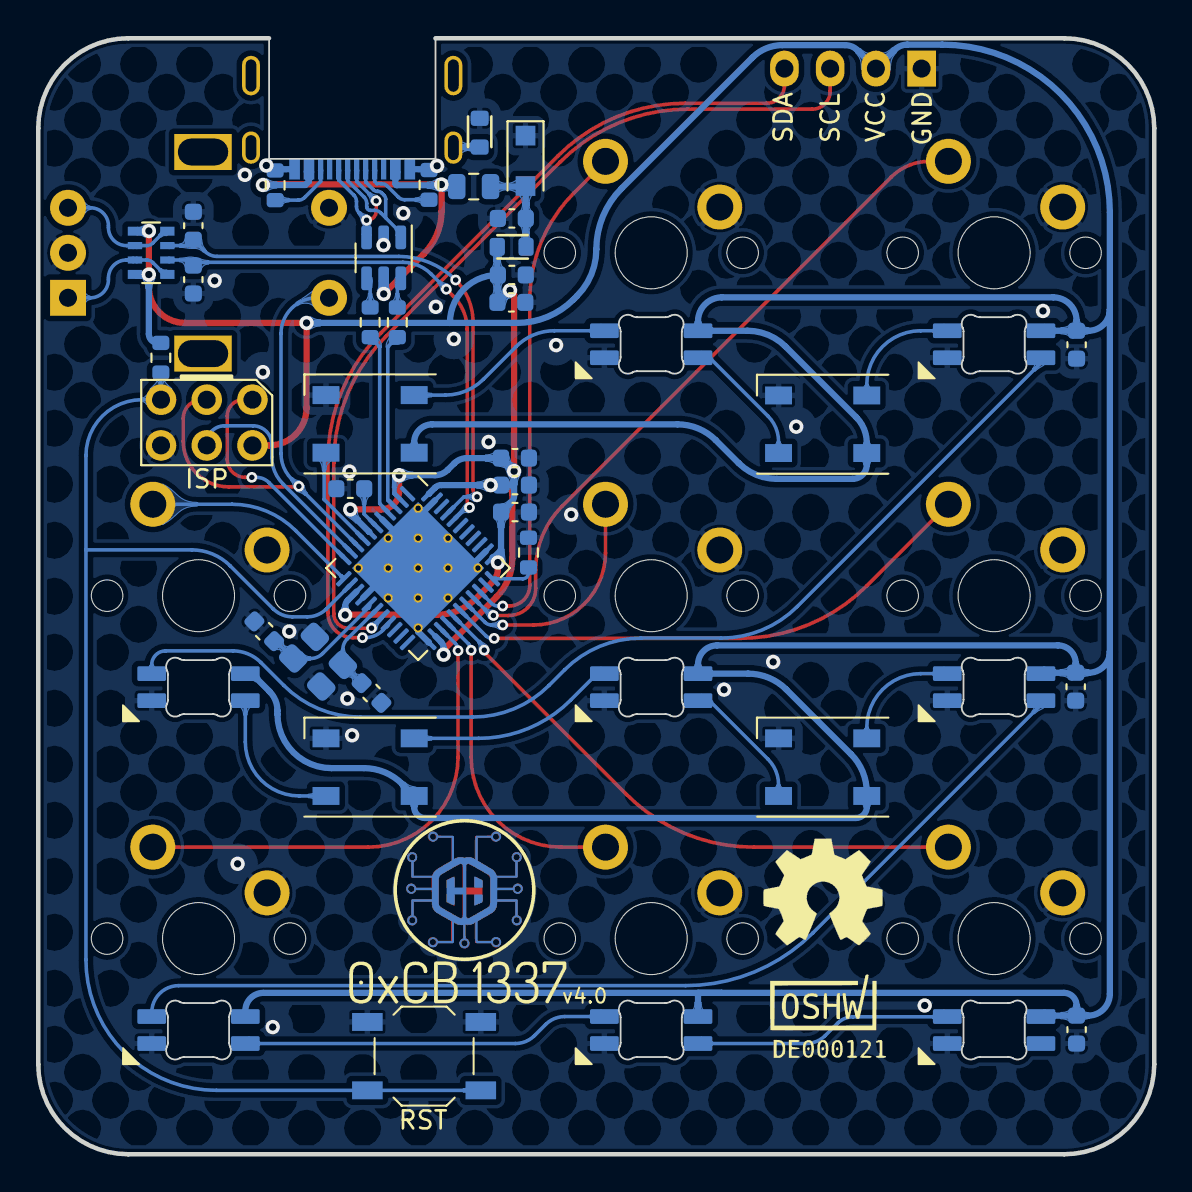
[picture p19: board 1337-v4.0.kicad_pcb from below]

Board: 2 copper layers, 62.0 x 62.0 mm, 55 parts (36 on the bottom side), 47 nets.

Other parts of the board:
kibuzzard-61BA68AC, kibuzzard-61BA68AC#2: G***; kibuzzard-61BA68AC

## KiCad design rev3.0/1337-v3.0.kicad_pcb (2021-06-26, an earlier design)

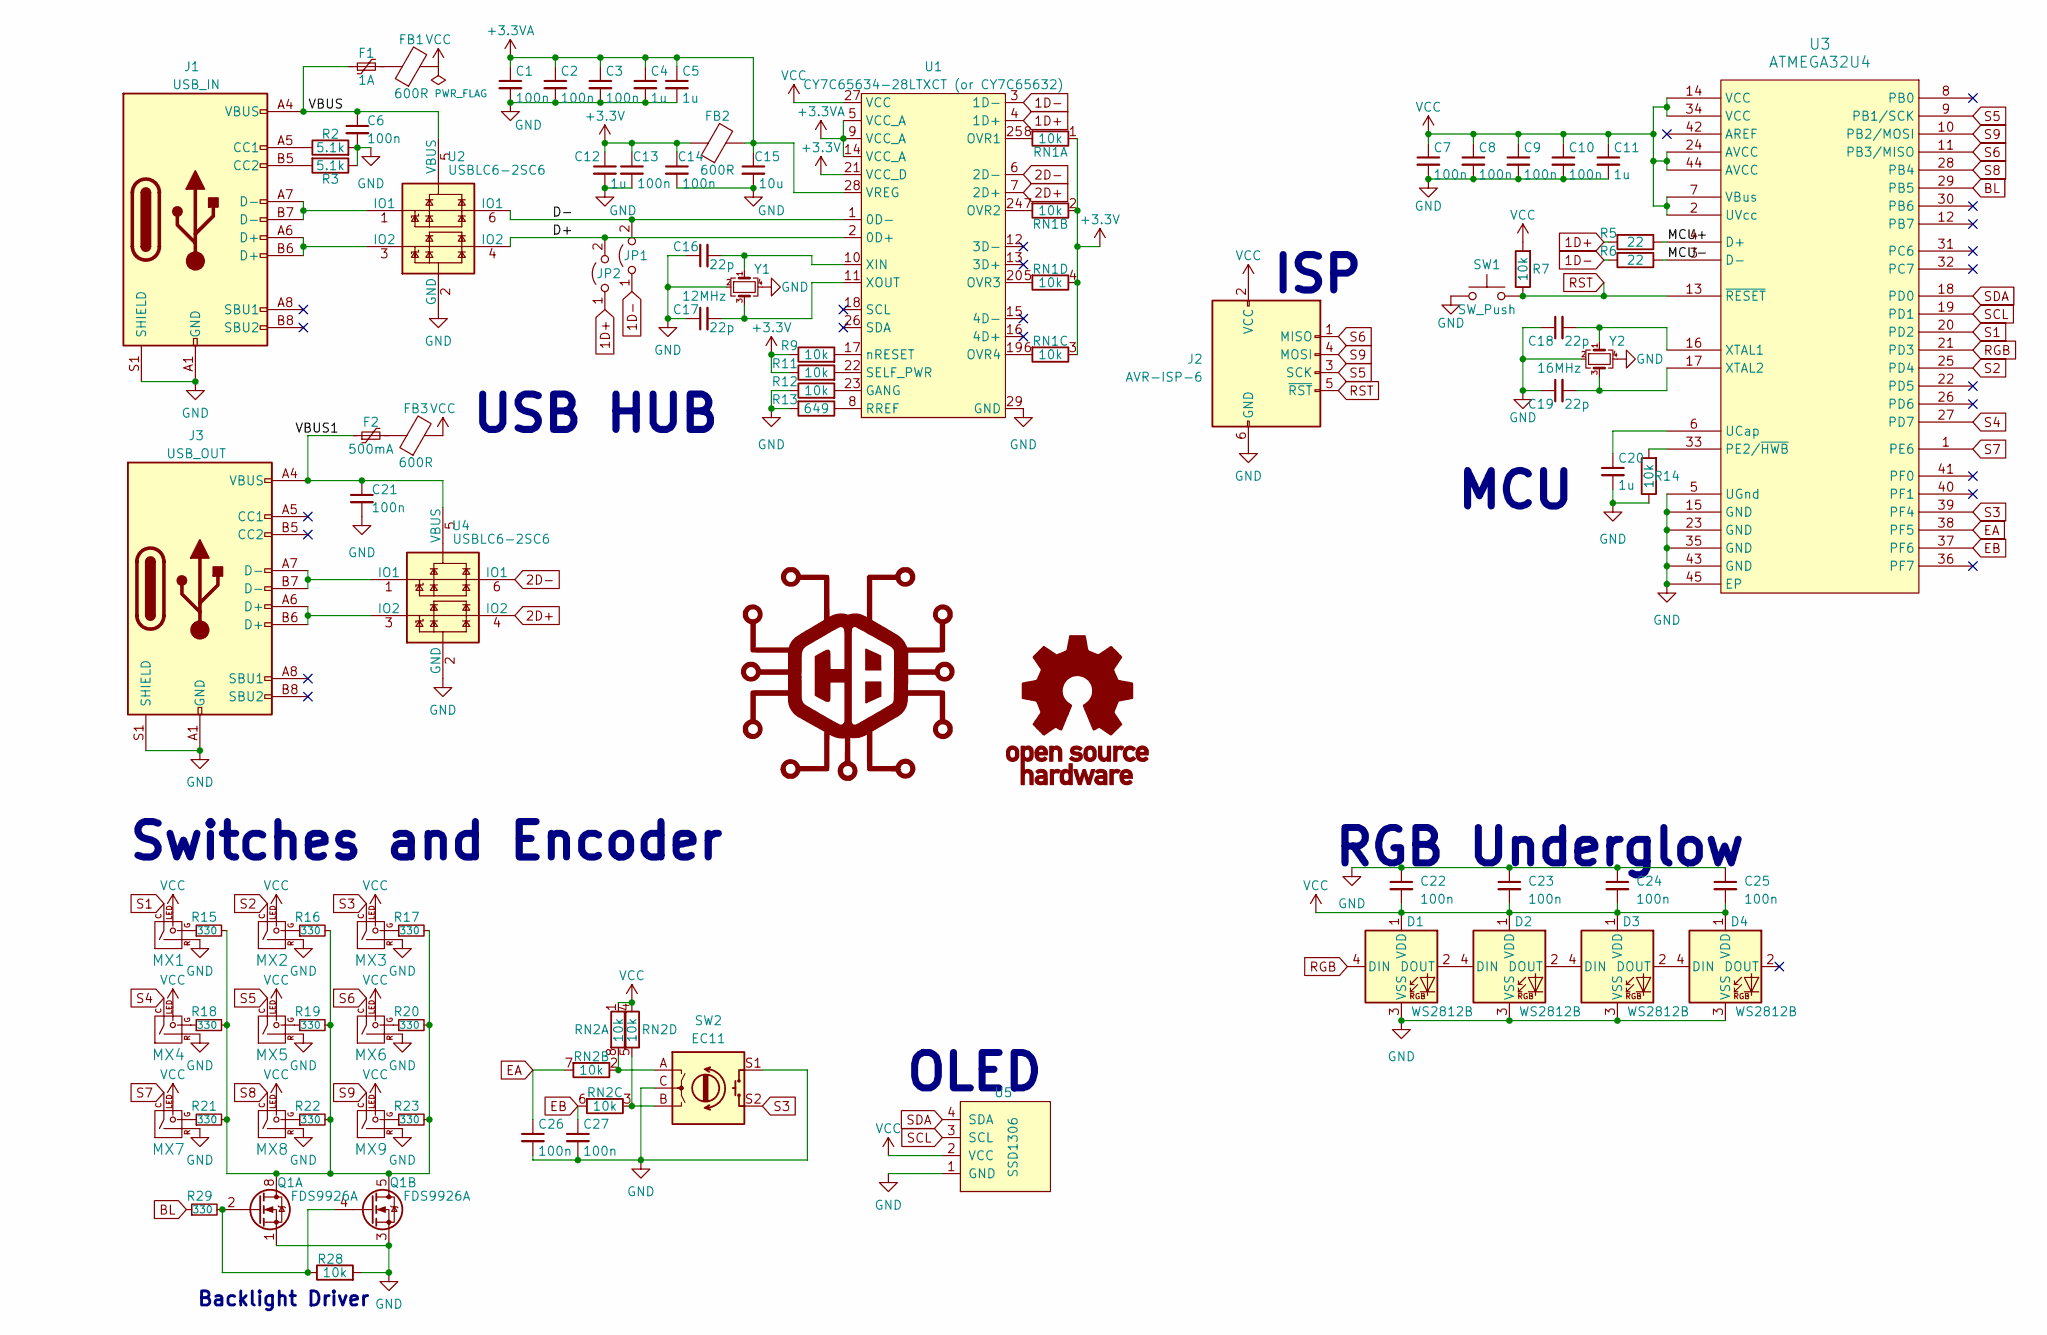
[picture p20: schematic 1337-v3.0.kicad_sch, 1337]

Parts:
C1, C2, C3, C6, C7, C8, C9, C10, C13, C14, C21, C22, C23, C24, C25, C26, C27: 100n; C_0603_1608Metric; Part Nb. 478-5266-1-ND
C4, C5, C11, C12, C20: 1u; C_0603_1608Metric; Part Nb. 1276-1102-1-ND
C15: 10u; C_0603_1608Metric; Part Nb. 587-3383-1-ND
C16, C17, C18, C19: 22p; C_0603_1608Metric; Part Nb. 478-1167-1-ND
D1, D2, D3, D4: WS2812B; LED_WS2812B_PLCC4_5.0x5.0mm_P3.2mm; Part Nb. 1568-COM-16347CT-ND
F1: 1A; Fuse_0805_2012Metric; Part Nb. 507-1815-1-ND
F2: 500mA; Fuse_0805_2012Metric; Part Nb. 507-1813-1-ND
FB1, FB2, FB3: 600R; Ferrite_Bead_0603; Part Nb. 732-1593-1-ND
J1: USB_IN; HRO-TYPE-C-31-M-13; Part Nb. 900-2169900002CT-ND
J2: AVR-ISP-6; AVR_PROG_2.54_THT
J3: USB_OUT; HRO-TYPE-C-31-M-13; Part Nb. 900-2169900002CT-ND
JP1, JP2: Jumper_2_Open; R_0201_0603Metric
L1: LOGO; logo
L2: OSHW; oshw
MX1, MX2, MX3, MX4, MX5, MX6, MX7, MX8, MX9: MX-LED; MXOnly-1U; Part Nb. CH310-ND
Q1: FDS9926A; SOIC-8_3.9x4.9mm_P1.27mm; Part Nb. FDS9926ACT-ND
R2, R3: 5.1k; R_0603_1608Metric; Part Nb. P5.1KDBCT-ND
R5, R6: 22; R_0603_1608Metric; Part Nb. A130081CT-ND
R7, R9, R11, R12, R14, R28: 10k; R_0603_1608Metric; Part Nb. RHM10KADCT-ND
R13: 649; R_0603_1608Metric; Part Nb. P649DBCT-ND
R15, R16, R17, R18, R19, R20, R21, R22, R23, R29: 330; R_1206_3216Metric; Part Nb. A130532CT-ND
RN1, RN2: 10k; R_Array_Convex_4x0603; Part Nb. MNR14103RTR-ND
SW1: SW_Push; SW_SPST_TL3342; Part Nb. EG2531CT-ND
SW2: EC11; RotaryEncoder_Alps_EC11E; Part Nb. PEC11L-4125F-S0020-ND
U1: CY7C65634-28LTXCT (or CY7C65632); QFN-28-1EP_5x5mm_P0.5mm_EP3.35x3.35mm_ThermalVias; Part Nb. 428-3154-1-ND
U2, U4: USBLC6-2SC6; SOT-23-6; Part Nb. 497-5235-1-ND
U3: ATMEGA32U4; QFN-44-1EP_7x7mm_P0.5mm_EP5.2x5.2mm_ThermalVias; Part Nb. ATMEGA32U4RC-MURCT-ND
U5: SSD1306; 128x64OLED
Y1: 12MHz; Crystal_SMD_3225-4Pin_3.2x2.5mm; Part Nb. XC2874CT-ND
Y2: 16MHz; Crystal_SMD_3225-4Pin_3.2x2.5mm; Part Nb. XC2060CT-ND

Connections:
1D+: JP2.1 (A), R5.2, U1.4 (1D+)
1D-: JP1.1 (A), R6.2, U1.3 (1D-)
2D+: U1.7 (2D+), U4.4 (IO2)
2D-: U1.6 (2D-), U4.6 (IO1)
+3.3VA: C1.1, C2.1, C3.1, C4.1, C5.1, C15.1, FB2.2, U1.5 (VCC_A), U1.9 (VCC_A), U1.14 (VCC_A), U1.28 (VREG)
+3V3: C12.1, C13.1, C14.1, FB2.1, R9.1, R11.1, RN1.1 (R1.1), RN1.2 (R2.1), RN1.3 (R3.1), RN1.4 (R4.1), U1.21 (VCC_D)
/D+: JP2.2 (B), U1.2 (0D+), U2.4 (IO2)
/D-: JP1.2 (B), U1.1 (0D-), U2.6 (IO1)
/MCU+: R5.1, U3.4 (D+)
/MCU-: R6.1, U3.3 (D-)
/VBUS: C6.1, F1.1, J1.A4 (VBUS), J1.A9 (VBUS), J1.B4 (VBUS), J1.B9 (VBUS), U2.5 (VBUS)
/VBUS1: C21.1, F2.1, J3.A4 (VBUS), J3.A9 (VBUS), J3.B4 (VBUS), J3.B9 (VBUS), U4.5 (VBUS)
BL: R29.1, U3.29 (PB5)
EA: C26.1, RN2.7 (R2.2), U3.38 (PF5)
EB: C27.1, RN2.6 (R3.2), U3.37 (PF6)
GND: C1.2, C2.2, C3.2, C4.2, C5.2, C6.2, C7.2, C8.2, C9.2, C10.2, C11.2, C12.2, C13.2, C14.2, C15.2, C16.1, C17.1, C18.1, C19.1, C20.2, C21.2, C22.1, C23.1, C24.1, C25.1, C26.2, C27.2, D1.3 (VSS), D2.3 (VSS), D3.3 (VSS), D4.3 (VSS), J1.A1 (GND), J1.A12 (GND), J1.B1 (GND), J1.B12 (GND), J1.S1 (SHIELD), J2.6 (GND), J3.A1 (GND), J3.A12 (GND), J3.B1 (GND), J3.B12 (GND), J3.S1 (SHIELD), MX1.2 (ROW), MX2.2 (ROW), MX3.2 (ROW), MX4.2 (ROW), MX5.2 (ROW), MX6.2 (ROW), MX7.2 (ROW), MX8.2 (ROW), MX9.2 (ROW), Q1.1 (S1), Q1.3 (S2), R2.2, R3.1, R12.1, R13.2, R14.1, R28.2, SW1.1, SW2.C, SW2.S1, U1.29 (GND), U2.2 (GND), U3.5 (UGnd), U3.15 (GND), U3.23 (GND), U3.35 (GND), U3.43 (GND), U3.45 (EP), U4.2 (GND), U5.1 (GND), Y1.2, Y1.4, Y2.2, Y2.4
unnamed: C16.2, U1.10 (XIN), Y1.1
unnamed: C17.2, U1.11 (XOUT), Y1.3
unnamed: C18.2, U3.16 (XTAL1), Y2.1
unnamed: C19.2, U3.17 (XTAL2), Y2.3
unnamed: C20.1, U3.6 (UCap)
unnamed: D1.2 (DOUT), D2.4 (DIN)
unnamed: D2.2 (DOUT), D3.4 (DIN)
unnamed: D3.2 (DOUT), D4.4 (DIN)
unnamed: F1.2, FB1.1
unnamed: F2.2, FB3.1
unnamed: J1.A5 (CC1), R2.1
unnamed: J1.A6 (D+), J1.B6 (D+), U2.3 (IO2)
unnamed: J1.A7 (D-), J1.B7 (D-), U2.1 (IO1)
unnamed: J1.B5 (CC2), R3.2
unnamed: J3.A6 (D+), J3.B6 (D+), U4.3 (IO2)
unnamed: J3.A7 (D-), J3.B7 (D-), U4.1 (IO1)
unnamed: MX1.4 (LEDGND), R15.1
unnamed: MX2.4 (LEDGND), R16.1
unnamed: MX3.4 (LEDGND), R17.1
unnamed: MX4.4 (LEDGND), R18.1
unnamed: MX5.4 (LEDGND), R19.1
unnamed: MX6.4 (LEDGND), R20.1
unnamed: MX7.4 (LEDGND), R21.1
unnamed: MX8.4 (LEDGND), R22.1
unnamed: MX9.4 (LEDGND), R23.1
unnamed: Q1.2 (G1), Q1.4 (G2), R28.1, R29.2
unnamed: Q1.5 (D2), Q1.6 (D2), Q1.7 (D1), Q1.8 (D1), R15.2, R16.2, R17.2, R18.2, R19.2, R20.2, R21.2, R22.2, R23.2
unnamed: R9.2, U1.17 (nRESET)
unnamed: R11.2, U1.22 (SELF_PWR)
unnamed: R12.2, U1.23 (GANG)
unnamed: R13.1, U1.8 (RREF)
unnamed: R14.2, U3.33 (PE2/~HWB)
unnamed: RN1.5 (R4.2), U1.20 (OVR3)
unnamed: RN1.6 (R3.2), U1.19 (OVR4)
unnamed: RN1.7 (R2.2), U1.24 (OVR2)
unnamed: RN1.8 (R1.2), U1.25 (OVR1)
unnamed: RN2.2 (R2.1), RN2.8 (R1.2), SW2.A
unnamed: RN2.3 (R3.1), RN2.5 (R4.2), SW2.B
RGB: D1.4 (DIN), U3.21 (PD3)
RST: J2.5 (~RST), R7.1, SW1.2, U3.13 (~RESET)
S1: MX1.1 (COL), U3.20 (PD2)
S2: MX2.1 (COL), U3.25 (PD4)
S3: MX3.1 (COL), SW2.S2, U3.39 (PF4)
S4: MX4.1 (COL), U3.27 (PD7)
S5: J2.3 (SCK), MX5.1 (COL), U3.9 (PB1/SCK)
S6: J2.1 (MISO), MX6.1 (COL), U3.11 (PB3/MISO)
S7: MX7.1 (COL), U3.1 (PE6)
S8: MX8.1 (COL), U3.28 (PB4)
S9: J2.4 (MOSI), MX9.1 (COL), U3.10 (PB2/MOSI)
SCL: U3.19 (PD1), U5.3 (SCL)
SDA: U3.18 (PD0), U5.4 (SDA)
VCC: C7.1, C8.1, C9.1, C10.1, C11.1, C22.2, C23.2, C24.2, C25.2, D1.1 (VDD), D2.1 (VDD), D3.1 (VDD), D4.1 (VDD), FB1.2, FB3.2, J2.2 (VCC), MX1.3 (LED), MX2.3 (LED), MX3.3 (LED), MX4.3 (LED), MX5.3 (LED), MX6.3 (LED), MX7.3 (LED), MX8.3 (LED), MX9.3 (LED), R7.2, RN2.1 (R1.1), RN2.4 (R4.1), U1.27 (VCC), U3.2 (UVcc), U3.7 (VBus), U3.14 (VCC), U3.24 (AVCC), U3.34 (VCC), U3.44 (AVCC), U5.2 (VCC)

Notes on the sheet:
Backlight Driver
USB HUB
Switches and Encoder
OLED
ISP
MCU
RGB Underglow

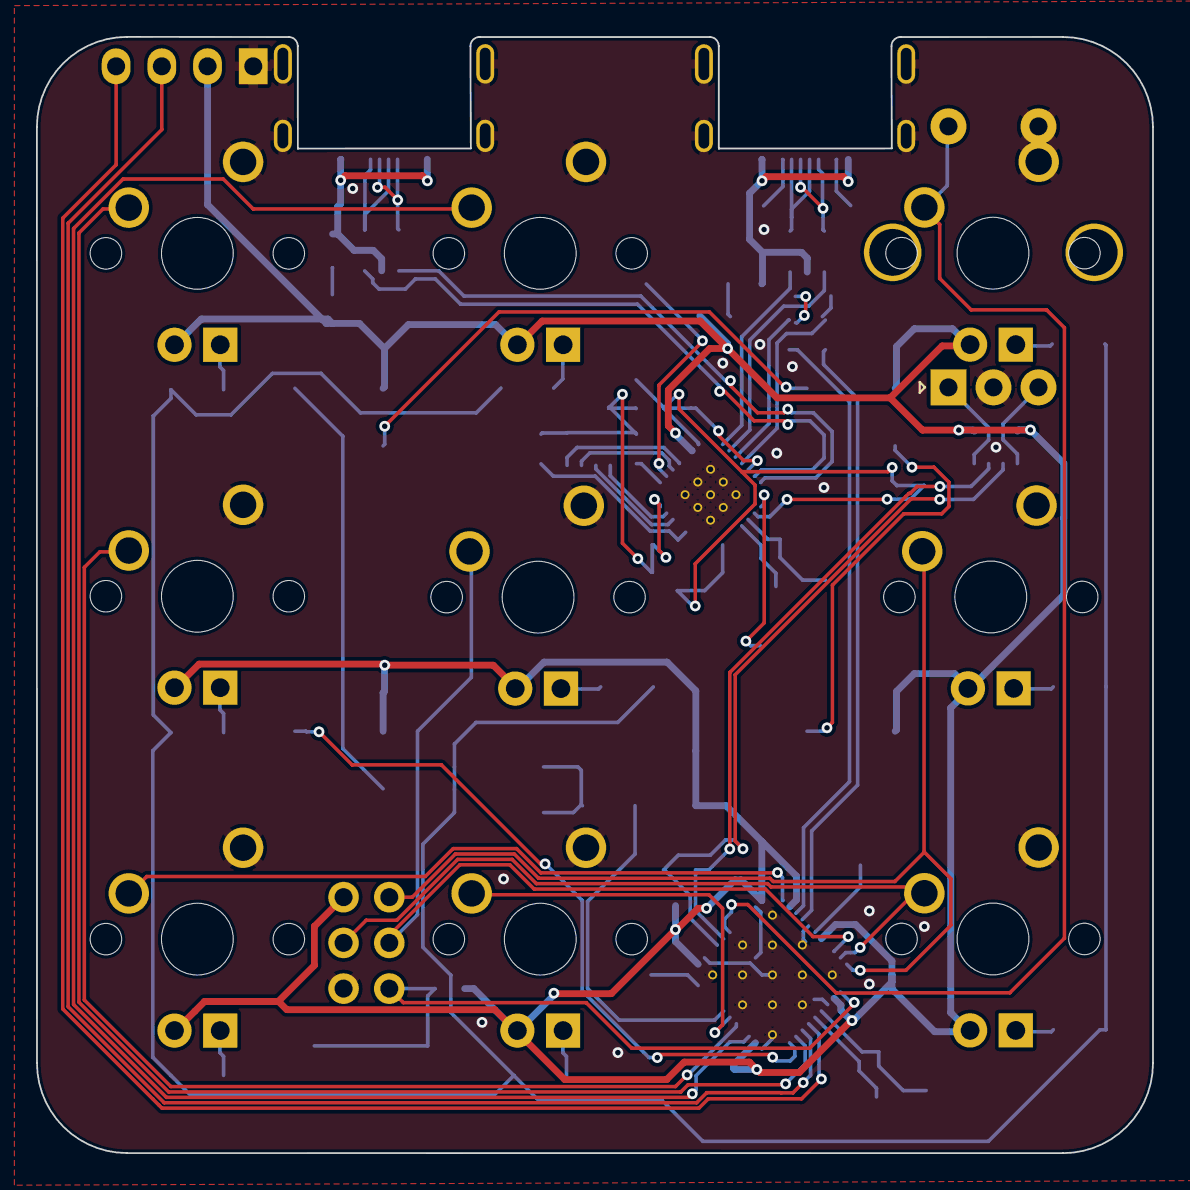
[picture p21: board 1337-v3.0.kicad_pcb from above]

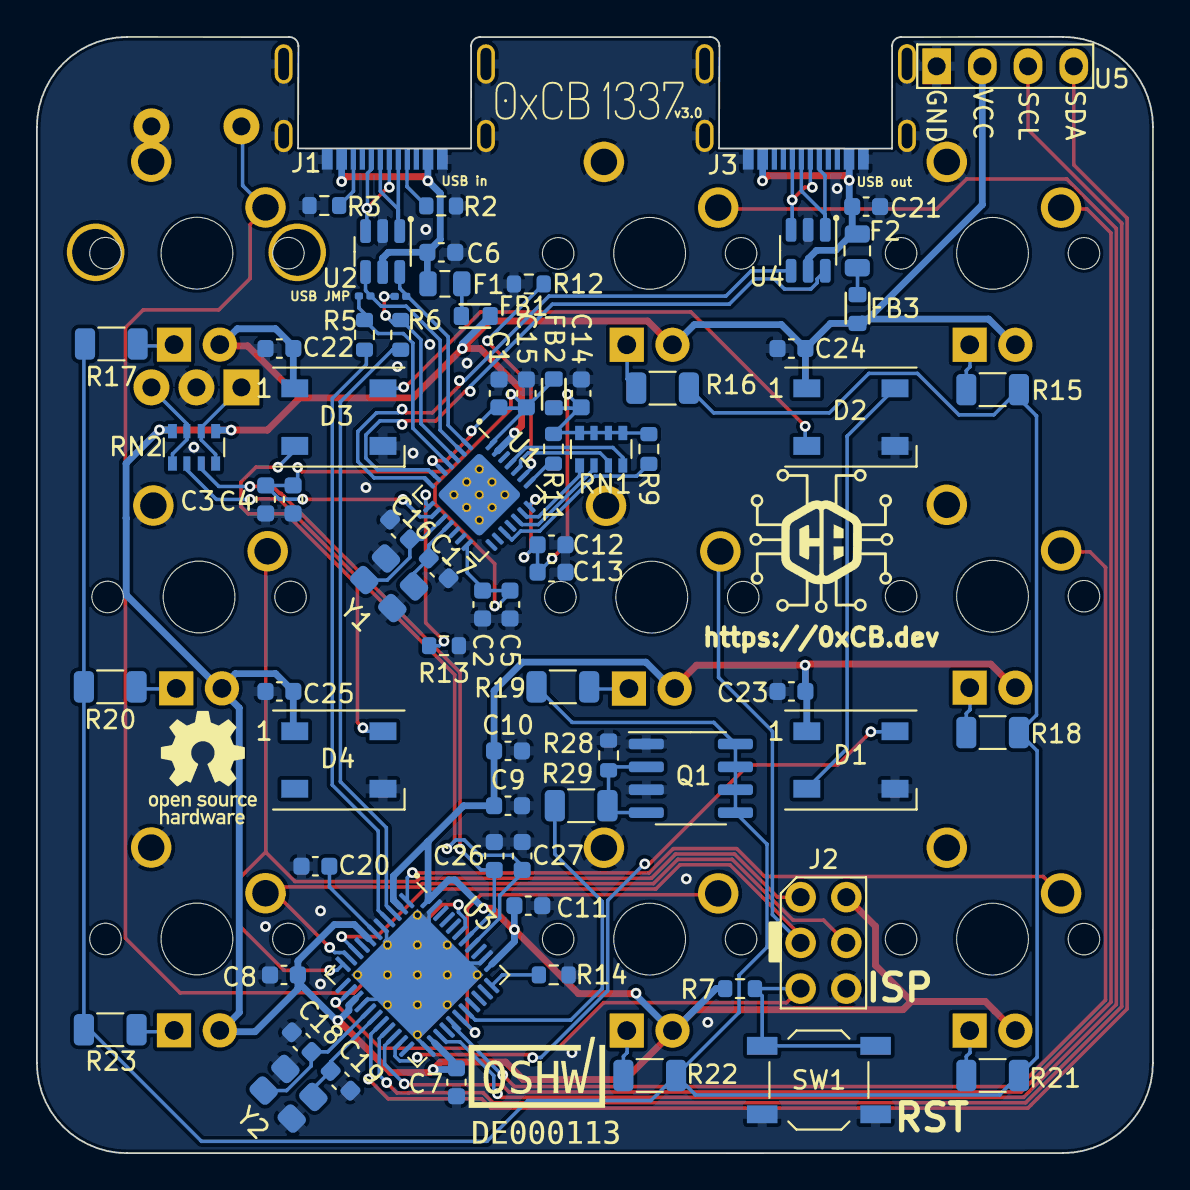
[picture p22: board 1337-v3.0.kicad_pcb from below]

Board: 2 copper layers, 62.0 x 62.0 mm, 87 parts (77 on the bottom side), 68 nets.

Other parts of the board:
L***: oshwa
svg2mod: G***; svg2mod

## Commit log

2021-03-02 added licence and updated revision for better traces and smd componets + ISP flash header for easier flashing
2021-05-24 added rev2.1
    [rev2.1.kicad_pcb, rev2.1.kicad_sch]
2021-05-28 update bom
    [1337-v3.0.csv, 1337-v3.0.kicad_sch]
2021-05-30 updated bom
    [1337-v3.0.csv]
2021-06-26 updated readme bom
    [1337-v3.0-B_Cu.gbr, 1337-v3.0-B_Mask.gbr, 1337-v3.0-B_Paste.gbr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]
2021-12-13 added V4 WIP
    [1337-v3.0-B_Cu.gbr, 1337-v3.0-B_Mask.gbr, 1337-v3.0-B_Paste.gbr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]
2021-12-15 traced PCB
    [1337-v4.0.kicad_pcb, 1337-v4.0.kicad_sch]
2021-12-15 rounded traces, added logo etc
    [1337-v4.0.kicad_pcb, 1337-v4.0.kicad_sch]
2021-12-15 prod push
    [1337-v4.0-B_Cu.gbr, 1337-v4.0-B_Mask.gbr, 1337-v4.0-B_Paste.gbr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]
2022-01-07 finalizing v4.0
    [1337-v4.0-B_Cu.gbr, 1337-v4.0-B_Mask.gbr, 1337-v4.0-B_Paste.gbr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]
2022-01-07 fixing Readme
    [1337-v4.0.kicad_sch]
2022-01-07 updated BOM for v4.0
2022-01-07 added teardrops
    [1337-v4.0-B_Cu.gbr, 1337-v4.0-B_Mask.gbr, 1337-v4.0-B_Paste.gbr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]
2022-01-07 added gitignore
    [1337-v3.0.kicad_sch]
2022-01-07 added case models
    [Assembly.SLDASM, Bottom.SLDPRT, Bottom.STL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]
2022-01-08 added 3D PCB models
    [1337-v4.0-B_Silkscreen.dxf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]
2022-01-09 added OSHWA mark and exported prod files
    [1337-v4.0.kicad_pcb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]
2022-08-24 updated git
    [Assembly.SLDASM, Bottom.SLDPRT, Bottom.STL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]
2023-04-26 rev5 init
    [bom.csv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]
2023-04-27 added flex cable
    [pcb-Edge_Cuts.gbr, pcb-F_Cu.gbr, pcb-F_Mask.gbr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]
2023-04-27 prod file generation
    [bom.csv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]
2023-05-29 fix some minor issues
    [bom.csv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]
2023-06-28 fix flex and expose GPIOs
    [pcb-B_Cu.gbr, pcb-B_Mask.gbr, pcb-B_Paste.gbr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]
